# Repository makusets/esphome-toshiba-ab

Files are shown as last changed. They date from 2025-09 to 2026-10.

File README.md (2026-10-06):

# ESPHome Toshiba AB

ESPHome hardware and component support for Toshiba central air-conditioning and
ESTIA hydronic heat-pump systems that communicate over the two-wire **AB bus**.

> This project is not suitable for most split systems that are controlled only
> by an infrared remote.

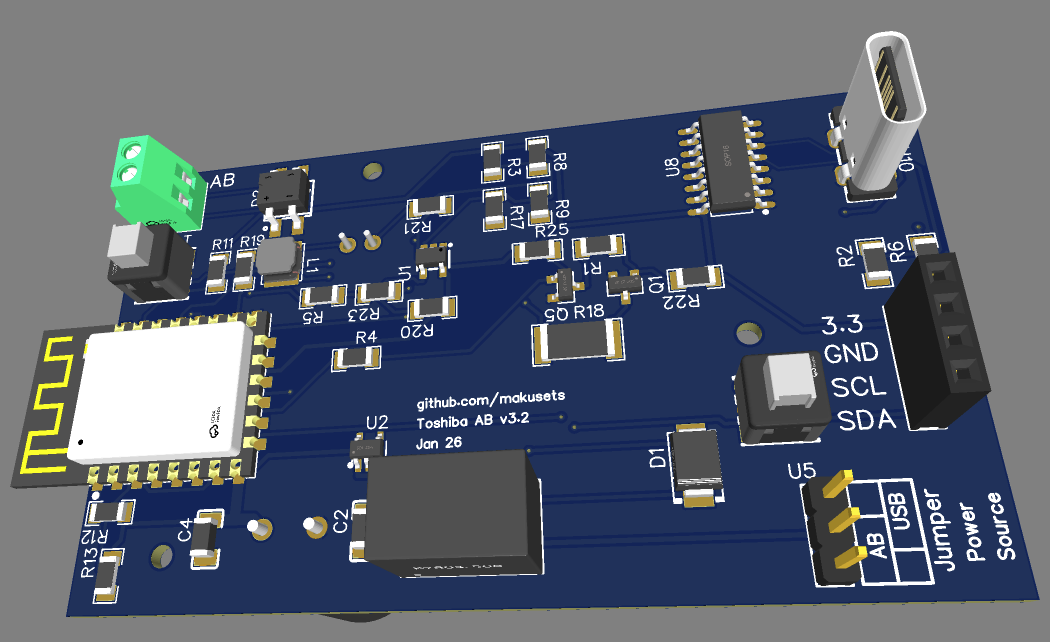
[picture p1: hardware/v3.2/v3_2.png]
Toshiba AB v3.2 board
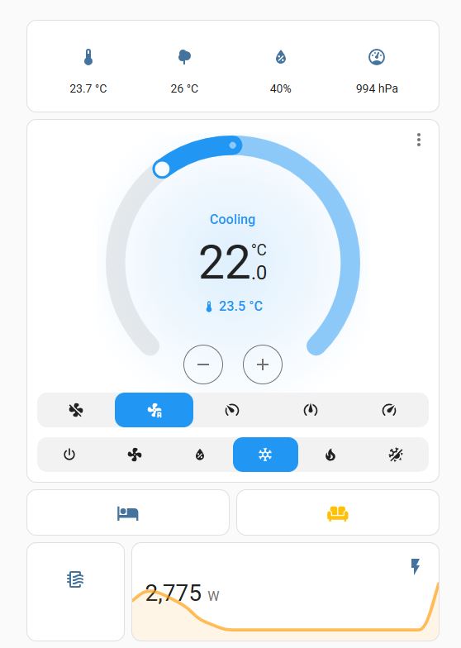
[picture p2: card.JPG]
Assembled Toshiba AB board
 

## Changelog

### July 2026 — TU2C and ESTIA R410A support

The TU2C protocol is now fully functional, thanks to contributions from
[@yvertman](https://github.com/yvertman) and
[@Dieghito72](https://github.com/Dieghito72).

Thanks to [@JuhaniVu](https://github.com/JuhaniVu), the first-generation Toshiba
ESTIA R410A frame format is fully implemented. Select `frame_format: estia` and
use a 2400 baud, 8N1 UART (`parity: NONE`). See the
[complete R410A configuration](estia_R410A.yaml).

### May 2026 — ESTIA R32 and protocol improvements

Thanks to [@7tobias](https://github.com/7tobias), Toshiba R32 ESTIA Series 1
systems are supported. The component can detect the normal TCC-Link, HM and
ESTIA R32/A0 formats, and address assignment avoids duplicate-address E09
errors. Thanks to [@mtthidoteu](https://github.com/mtthidoteu), HM-format support
and hardware UART operation improve compatibility and stability.

### January 2026 — autonomous mode

The component can operate without another wall controller, supports configurable
commercial-system read/write command modes and a filter-alert sensor, and has
more robust frame handling and logging. See the relevant complete YAML example
below for the optional settings.

### Hardware releases

- **v3.2:** revised UART pins, a 3300 µF 3.3 V rail capacitor, easier-to-solder
  USB-C, boot/reset buttons, a power-selection jumper and easier assembly.
- **D1 mini:** a simpler board designed with
  [@issalig](https://github.com/issalig), using RX D7 and TX D8.
- **v3:** wider AB-line voltage range, improved filtering, a comparator-based
  receiver and selectable AB/USB power.

## About this project

The component decodes traffic between a Toshiba indoor unit and its wired remote,
reports the system to ESPHome/Home Assistant, and sends commands as a wall remote
would. It supports:

- conventional **air-to-air systems** using classic TCC-Link, its HM variation,
  or the now fully functional TU2C protocol;
- **ESTIA hydronic systems**, including tested R410A and R32 generations;
- operation alongside a wall remote or, where supported, autonomous operation.

The hardware is an ESP8266/ESP-12 interface board designed in EasyEDA. It powers
from the AB line (or USB for initial flashing only, no comms) and converts the AB bus to
UART safely. **Do not connect the AB terminals directly to an ESP UART.**

### Hardware requirements and application range

You need a supported ESPHome board/interface from the [`hardware`](hardware/)
folder (or an electrically equivalent reader/writer circuit), access to the
unit's wired **A/B remote terminals**, and an ESPHome/Home Assistant installation.
The current board has been used with Toshiba central/commercial HVAC, multi-split
indoor units that expose an AB wired-controller connection, and ESTIA heat pumps.

Model names are useful hints, not guarantees: Toshiba has used different
protocols within related product ranges. Confirm that your unit has an AB port,
then use the selection tables below and the
[protocol/frame-format reference](docs/frame_formats.md).

## Start here: flash and connect the board

These essential installation steps are deliberately kept visible rather than
inside a collapsible section. Read the complete [hardware guide](docs/hardware.md)
before building a board or substituting components.

### 1. Flash ESPHome over USB

1. Start with [`example.yaml`](example.yaml), or copy the minimal configuration
   from the air-to-air/ESTIA section below. Add your normal ESPHome Wi-Fi, API,
   OTA and secrets settings.
2. Select the UART pins for your board: v3.2 uses TX `GPIO12` and RX `GPIO13`;
   v3 uses TX `GPIO10` and RX `GPIO13`; v1 uses TX `GPIO15` and RX `GPIO13`;
   D1 mini uses TX `D8` and RX `D7`. Also select the parity and optionally the
   `frame_format` required by your AC system in the tables below.
4. **Leave the AC's A/B wires disconnected.** With all power removed, put the
   board's power-selection jumper/switch (if fitted) in the **USB** position,
   then attach it to the computer with a data-capable USB cable.
5. In the ESPHome dashboard, open the device and choose **Install → Plug into
   this computer**, or run `esphome run your-device.yaml` from the ESPHome CLI
   and select the USB serial port. Follow ESPHome's
   [first-device connection guide](https://esphome.io/guides/physical_device_connection/)
   if the serial device is not detected.
6. For v3.2, if flashing does not start, disconnect USB, hold **BOOT**, reconnect
   USB while continuing to hold **BOOT**, and retry the installation. When the
   upload finishes, confirm that the device boots, joins Wi-Fi and appears in
   ESPHome/Home Assistant. Later firmware updates can be installed over Wi-Fi.

### 2. Connect the board to the AC system

> **Electrical safety:** completely isolate the HVAC system at the distribution
> board before opening the wired controller or indoor unit. Hazardous voltages
> may be present nearby. Never connect the A/B bus directly to ESP UART pins.

1. Disconnect USB and switch off/isolate the complete HVAC system.
2. Remove the wired controller cover and locate its two **A/B remote-bus**
   terminals (or use the indoor unit's documented A/B controller terminals).
   Loosen the terminal screws without removing the existing controller wires.
3. Run a two-core cable from those A and B terminals to the board's A and B
   screw terminals. The v1 board is polarity-sensitive, so match A to A and B
   to B; v3 and v3.2 accept either polarity.
4. With both USB and the AC still disconnected, move the board's power selector
   (if fitted) to **AB**. Never move the selector while either power source is
   connected.
5. Check the wiring, refit the controller cover, restore HVAC power, and inspect
   the ESPHome logs for valid frames and a connected state before sending any
   commands.

The board is connected **in parallel** with the wired controller; it does not
replace or interrupt the existing A/B pair. Autonomous operation without a wall
controller is an advanced option documented in
[`complete_example.yaml`](complete_example.yaml).

The A/B screws on a typical wired-controller PCB look like this:

A/B terminals on the back of a Toshiba wired controller

<details>
<summary><strong>Hardware design, construction, installation and case</strong></summary>

The recommended v3.2 board includes AB-line power conversion, noise filtering,
a comparator receiver and a transistor writer. Isolate the HVAC system before
opening a controller or changing AB wiring. Select USB power for initial flashing
and AB power only after USB power has been disconnected.

Board fabrication files, schematics, bills of materials, assembly advice,
installation steps and enclosure details are collected in the
[hardware guide](docs/hardware.md). Go directly to a board revision:

- [v3.2](hardware/v3.2/README.md) — recommended full board
- [D1 mini](hardware/D1%20mini/README.md) — simpler modular variant
- [v3](hardware/v3/README.md) and [v1](hardware/v1/README.md) — older revisions
- [all hardware and printable case files](hardware/)

</details>

<details>
<summary><strong>Air-to-air systems (conventional air conditioning)</strong></summary>

### Choosing a protocol

Air-to-air units use one of three supported AB protocol variations:

| Variation | Typical systems and examples | UART | `frame_format` |
| --- | --- | --- | --- |
| **TCC-Link** | Most established central/commercial systems. Tested examples include indoor `RAV-SM1103DT-A` and `MMD-AP0366BHP1-E` with `RBC-AMT32E`/`RBC-AMT54E` controllers; repository reports also include `RAV-SM802BT-E`. | 2400 baud, **8E1** (`EVEN`) | `auto` (recommended) or `normal` |
| **HM (TCC-Link variation)** | Newer RAV-HM/RAV-RM systems. Examples reported in this repository include `RAV-RM801BTP-E` + `RAV-GM801ATP-E`, `RAV-RM801KRTP-E`, and `RAV-HM561KRTP-E`. HM retains TCC-Link semantics but uses a different envelope. | 2400 baud, **8E1** (`EVEN`) | `auto` or `hm` |
| **TU2C** | Common in newer **U-series** systems; examples include `RAS-M16U2MUVG`, `RAS-M24U2DVG-E` and `M07U2DVG-E`. TU2C support is fully functional, but it is not auto-detected. | 2400 baud, **8N1** (`NONE`) | `tu2c` |

For byte-level differences, aliases and detection behavior, read
[Toshiba AB protocol frame formats](docs/frame_formats.md).

### Minimal ESPHome configuration

This is the complete component-specific portion for TCC-Link and HM. Add your normal
ESPHome device, Wi-Fi, API and OTA sections. For TU2C, change both highlighted
settings to `parity: NONE` and `frame_format: tu2c`.

```yaml
logger:
  baud_rate: 0

external_components:
  - source: github://makusets/esphome-toshiba-ab

uart:
  tx_pin: GPIO12       # GPIO10 on v3; GPIO15 on v1; D8 on D1 mini
  rx_pin: GPIO13       # D7 on D1 mini
  baud_rate: 2400
  parity: EVEN         # NONE for TU2C
  rx_buffer_size: 2048

climate:
  - platform: toshiba_ab
    name: "Toshiba AC"
    id: toshiba_ac
    frame_format: auto # use tu2c for TU2C systems or hm for HM systems
```

See [`complete_example.yaml`](complete_example.yaml) for autonomous operation,
addresses, temperature reporting, diagnostic sensors, power estimation and all
other air-to-air options. [`example.yaml`](example.yaml) is a ready-to-edit,
smaller device configuration.

### Optional BME280

The boards expose I²C so a BME280 can publish local temperature, humidity and
pressure. Its temperature can also be sent to the air conditioner as the room
temperature. The relevant I²C, sensor and `report_sensor_temp` YAML belongs in
the example configuration rather than this overview; see
[`complete_example.yaml`](complete_example.yaml).

</details>

<details>
<summary><strong>Hydronic systems (Toshiba ESTIA)</strong></summary>

### Tested generations and protocols

ESTIA changed protocol between the R410A and R32 generations. Both are supported,
but their UART parity and frame-format settings are not interchangeable.

| Generation | Protocol | Example/tested models | UART | `frame_format` |
| --- | --- | --- | --- | --- |
| **R410A / first generation** | First-generation ESTIA, TU2C-style wrapped frames | R410A ESTIA systems using first-generation wired controllers | 2400 baud, **8N1** (`NONE`) | `estia` (must be explicit) |
| **R32** | ESTIA A0 protocol | Series 1 `HWT-1101HRW-E` outdoor + `HWT-1101XWHT9W-E` indoor; `HWT-1102S21SM3W-E` is also reported in the repository | 2400 baud, **8E1** (`EVEN`) | `a0` |

### Minimal R410A configuration

```yaml
uart:
  tx_pin: GPIO15
  rx_pin: GPIO13
  baud_rate: 2400
  parity: NONE

climate:
  - platform: toshiba_ab
    name: "Toshiba Estia R410A"
    frame_format: estia
```

Use [`estia_R410A.yaml`](estia_R410A.yaml) for the complete R410A configuration.

### Minimal R32 configuration

```yaml
uart:
  tx_pin: GPIO15
  rx_pin: GPIO13
  baud_rate: 2400
  parity: EVEN

climate:
  - platform: toshiba_ab
    name: "Toshiba Estia R32"
    frame_format: a0
```

Use [`example_estia.yaml`](example_estia.yaml) for the complete R32 configuration,
including optional demand emulation, sensors and runtime switches.

### Optional BME280

A BME280 may be connected to the board's I²C header to expose local temperature,
humidity and pressure in ESPHome. ESTIA-specific control and polling do not
require it. Keep the actual BME280 configuration in the appropriate complete
YAML file if you choose to add one.

</details>

## Credits and thanks

This project builds on the difficult protocol-decoding and initial hardware work
by [@issalig](https://github.com/issalig) in
[`toshiba_air_cond`](https://github.com/issalig/toshiba_air_cond), and the initial
ESPHome component by [@muxa](https://github.com/muxa) in
[`esphome-tcc-link`](https://github.com/muxa/esphome-tcc-link).

Special thanks to [@7tobias](https://github.com/7tobias) for ESTIA R32 support,
[@JuhaniVu](https://github.com/JuhaniVu) for first-generation/R410A ESTIA support,
[@mtthidoteu](https://github.com/mtthidoteu) for HM support and hardware UART
improvements, and [@yvertman](https://github.com/yvertman) and
[@Dieghito72](https://github.com/Dieghito72) for their contributions to fully
functional TU2C support. Thanks also to every contributor and tester who has
shared hardware findings, models, captures, code and documentation.

## Boards on eBay

If you are after a fully finished product, I usually have some fully assembled boards that I am happy to sell. Search for "makusets" on eBay.

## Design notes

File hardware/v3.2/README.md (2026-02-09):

# v3.2 Jan 2026
# Ordering or building the board

You will need to build the compatible hardware. This folder contains all necessary files. I designed the board using EasyEDA online editor (free). All files are EasyEDA compatible format.
easyEDA_project.zip file can be imported onto EasyEDA editor to open the project with schematics and board design, make sure you use the 3.2 version once the project has been imported.

Alternatively, you can order the board from places like JLCPCB. You will need the 3 files included:

  - Gerber_v3_2.zip: This is the gerber file for the physical design of the board, if you only one the board made, that's all you need.
  - BOM_v3_2.csv: Contains the list of components (BOM). (needed if you want the full circuit board populated)
  - PaP_v3_2.csv: The information on where to place the component on the board. (needed if you want the full circuit board populated)

When ordering, make sure all the components that you want included are selected in the list.
I placed the electrolytic capacitors on the bottom side, so this will typically not be mounted if you are ordering the board from JLCPCB or similar. These are easily sourced and soldered by hand.
Use the 3D view to double check that all components appear on the board in the right orientation.

Alternatively, import easyEDA_project.zip and adjust it project to your needs. 

## Component shortfall

It often happens that components are out of stock or become unavailable and need to be replaced when uploading the BOM file. If you are not comfortable in doing so,
JLCPCB have the option of "parts sourced by JLCPCB" instead of "by customer". That should make it easy to replace shortfalls. Otherwise, use the search option and look for an equivalent component, AI is your friend and can help you find equivalent parts if in doubt. The 3D view on the next page can be useful to double check that you made the right choice and if any component needs to be reoriented.
The K78xx DCDC buck is a critical component, the board works fine with a DEXU branded one, EVSUN not good as it introduces a lot of noise in the AB line. Have not tried other brands, if you do, let me know.



# DIY tips

The internet is full of electronics sodering instructional tips and videos. I have nothing to add there, but I believe the board can be built with a bit of practice and some basic equipment, including a good soldering iron.

I personally did not use any magnifying device, reflow oven, or special equipment.

The two big capacitors are meant to be soldered at the back of the board and bended on its side, the case was designed with this in mind.

# Schematic

This is the schematic of the board.

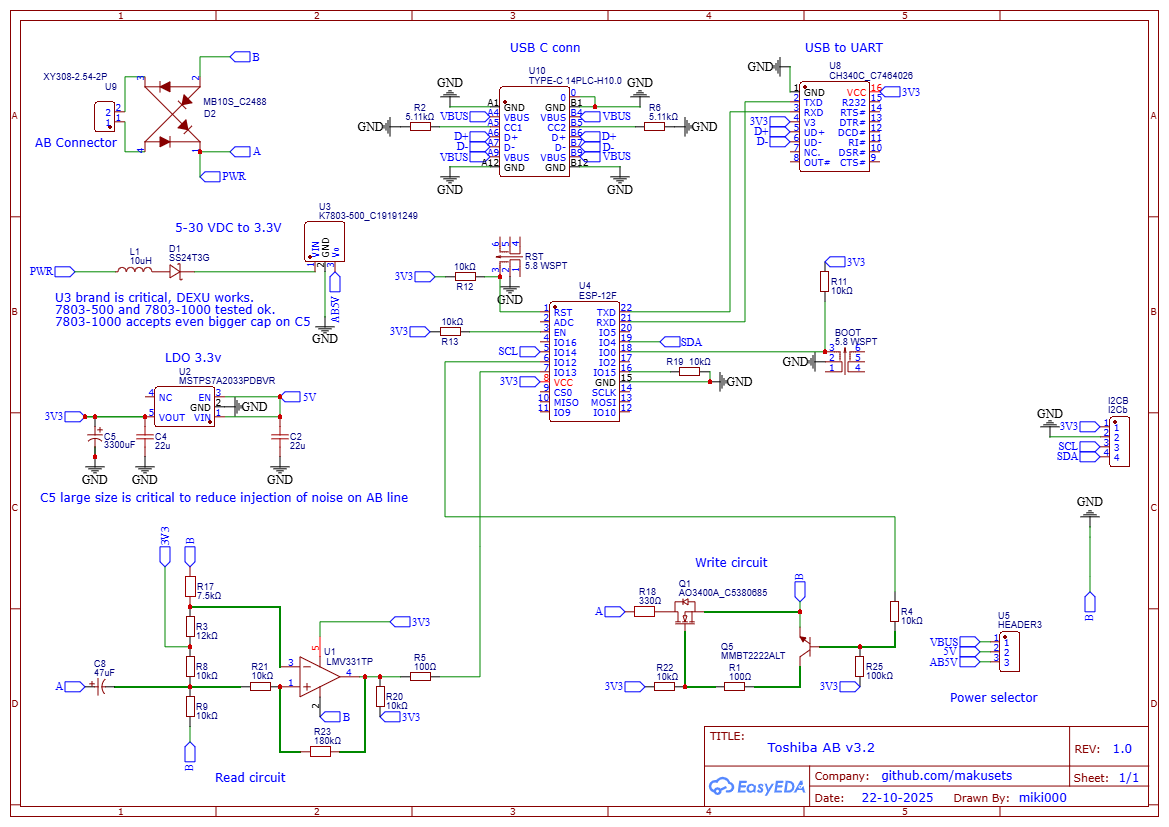
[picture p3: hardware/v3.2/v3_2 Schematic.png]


# Final product

This is how I installed it

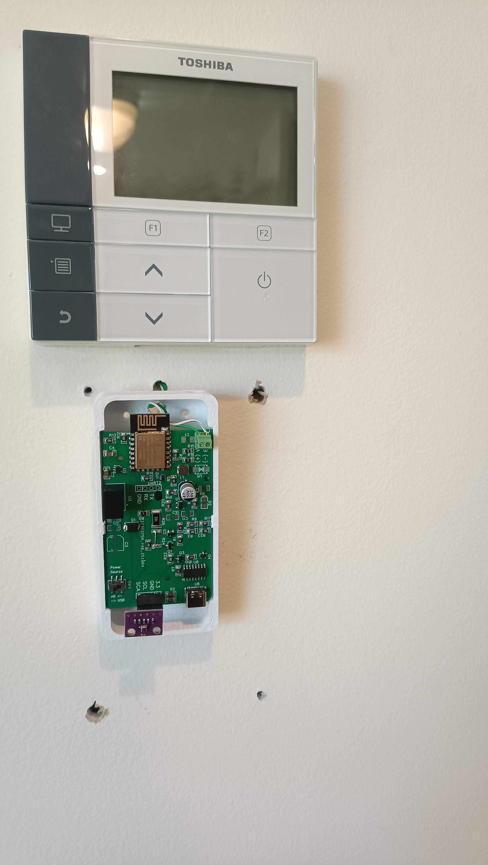
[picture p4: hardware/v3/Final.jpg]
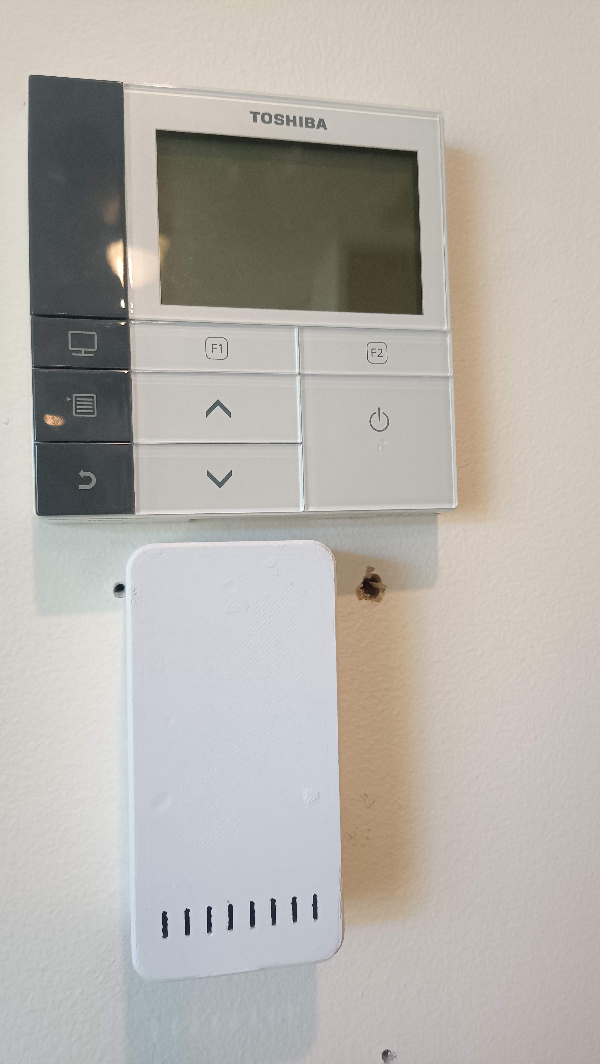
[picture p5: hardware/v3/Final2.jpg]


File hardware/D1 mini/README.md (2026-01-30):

# D1 mini Hardware

This folder contains the files required to build and assemble the D1 mini version of the board.

Contents

- `D1Mini.zip` — Gerber files for PCB fabrication (board layers, solder mask, silkscreen, drill files, etc.).
- `BOM_D1Mini.csv` — Bill of Materials: list of components, quantities and reference designators.
- `PP_D1Mini.csv` — Pick-and-place (Centroid) file used by automated assembly machines.
- `D1Mini.pdf` — Project schematic in PDF format.
- `D1Mini.png` — Project schematic as a PNG image (embedded below).

Notes

- Import the Gerber zip into your PCB manufacturer’s upload tool to produce PCBs.
- Use `BOM_D1Mini.csv` and `PP_D1Mini.csv` with your assembler or pick-and-place service.

# Schematic

The schematic for the D1 mini board is shown below.

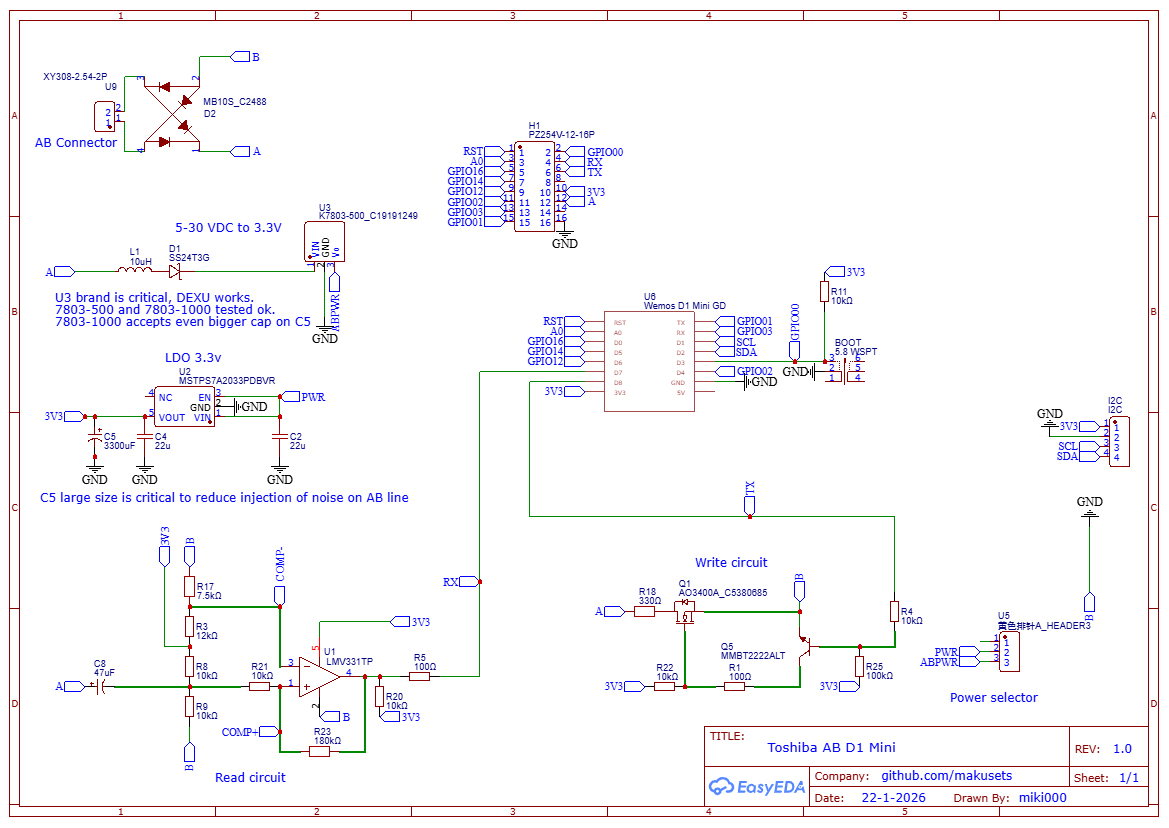
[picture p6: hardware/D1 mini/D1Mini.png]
D1 mini schematic


If the image does not render in your viewer, open `D1Mini.pdf` for a printable vector version.

---
Generated: January 30, 2026

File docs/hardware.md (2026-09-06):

# Toshiba AB hardware guide

The Toshiba AB bus is not a TTL UART. A reader/writer interface is required
between the A/B terminals and the ESP8266. This repository includes complete
fabrication files for several board revisions in the [`hardware`](../hardware/)
directory.

## Select a board

| Board | Use | UART pins | Documentation |
| --- | --- | --- | --- |
| v3.2 | Recommended integrated ESP-12 board | TX GPIO12, RX GPIO13 | [Build files and assembly](../hardware/v3.2/README.md) |
| D1 mini | Simpler modular board | TX D8, RX D7 | [Build files and assembly](../hardware/D1%20mini/README.md) |
| v3 | Previous integrated board | TX GPIO10, RX GPIO13 | [Build files and assembly](../hardware/v3/README.md) |
| v1 | Original board; polarity-sensitive AB input | TX GPIO15, RX GPIO13 | [Build files and assembly](../hardware/v1/README.md) |

Each board directory contains the available schematic, Gerbers, bill of
materials, pick-and-place data and/or editable EasyEDA project.

## Design

The v3/v3.2 design accepts the voltage range found on the AB line, filters power
and data noise, reads data through DC filtering and a comparator, and writes a
zero bit by pulling A toward B through a resistor, as Toshiba controllers do.
The bridge input makes these revisions insensitive to A/B polarity.

Wi-Fi current peaks are considerably higher than those of a wall controller.
For that reason the board uses a buck converter rather than only an LDO, followed
by a low-noise 3.3 V LDO and a large rail capacitor. The tested DEXU K7803-500 and
K7803-1000 converters work well. Component substitution—especially the buck
converter or filter capacitors—can introduce enough noise to corrupt AB traffic.

The I²C header supports an optional BME280 temperature, humidity and pressure
sensor, or another ESPHome-compatible I²C device.

## Building and first flash

1. Choose a board above and read its revision-specific README.
2. Upload its Gerber archive to a PCB fabricator. If ordering assembly, also
   supply that revision's BOM and pick-and-place file and verify component
   orientation in the fabricator's 3D preview.
3. Fit any through-hole capacitors or modules omitted by the assembly service.
4. For the first ESPHome flash, select **USB** power and connect USB. On v3.2,
   hold **BOOT** while applying USB power to enter flashing mode if necessary.
5. In the ESPHome dashboard choose **Install → Plug into this computer**, or run
   `esphome run your-device.yaml` and select the USB serial port. See ESPHome's
   [first-device connection guide](https://esphome.io/guides/physical_device_connection/)
   for USB driver and browser-installation details.
6. Confirm that the board boots and joins Wi-Fi. After the initial flash, normal
   updates can be installed over the air.

Never change the power selector while the board is powered. Disconnect both USB
and the AB line before moving the jumper or switch.

## Installation

> The indoor unit and wired controller may contain hazardous voltages nearby.
> Isolate the complete HVAC system at the distribution board before opening it.

1. Flash and validate the ESPHome board before connecting the AB line.
2. Completely isolate power to the HVAC system.
3. Remove the wired controller cover and loosen its A/B terminal screws, or use
   the unit's documented AB connection point. Leave the controller's existing
   wires in place: the interface board connects in parallel.
4. Wire A and B to the PCB. v1 is polarity-sensitive (A to A and B to B); v3 and
   v3.2 can be connected either way.
5. With USB disconnected, select **AB** power on boards that have a selector.
6. Reassemble the controller, restore HVAC power and inspect ESPHome logs for
   valid frames before sending commands.

The project emulates another wired controller. Address limits and coexistence
rules vary by system; avoid forcing addresses unless the normal auto-addressing
behavior does not work.

## Enclosure

A two-part printable enclosure is included in [`hardware/v3`](../hardware/v3/).
The v3.2 board fits the same case. STL files are ready for printing, and the
public Onshape source can be found by searching for `toshiba_esp_case` in
Onshape.

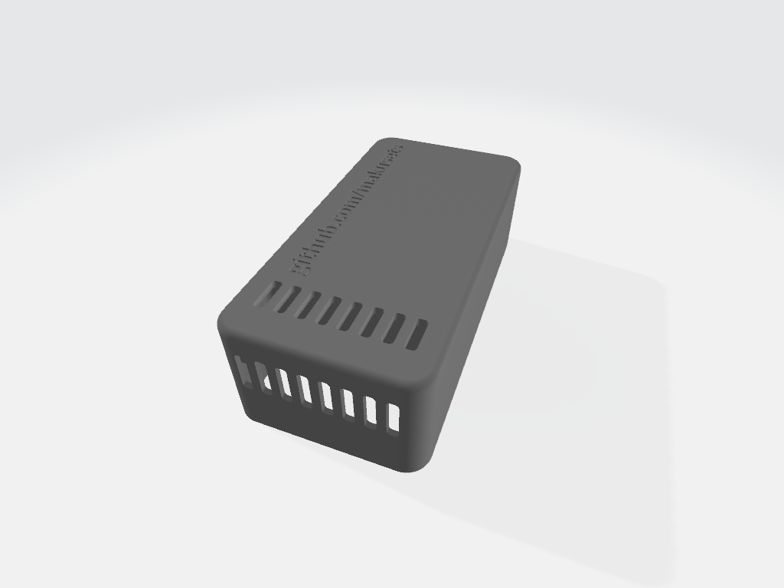
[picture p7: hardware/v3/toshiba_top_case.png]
Top of printable case
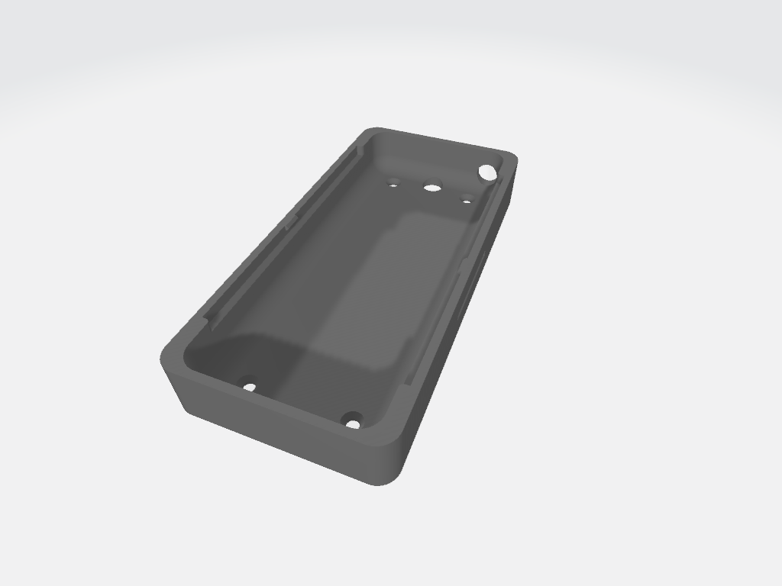
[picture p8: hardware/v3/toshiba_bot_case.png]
Bottom of printable case
 

## Next steps

Return to the [main README](../README.md) to select air-to-air or hydronic setup,
then use the correct UART parity and frame format for your system. Technical
protocol information is kept separately in
[`docs/frame_formats.md`](frame_formats.md).

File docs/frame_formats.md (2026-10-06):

# Toshiba AB protocols frame formats

This component can read several related Toshiba AB-bus protocols or frame formats. The default
configuration is `frame_format: auto`, which starts in the most common TCC-Link protocol
mode and switches to a more specific format if the component can identify one from live
traffic. Not all protocols are automatically identified.

## Quick selection guide

| `frame_format` value | Format | Typical use | UART parity | Auto-detected? | Notes |
| --- | --- | --- | --- | --- | --- |
| `auto` | Automatic | Recommended first try for most installs | See target format | N/A | Default. Starts as normal TCC-Link and confirms `normal` from traffic. |
| `n`, `normal`, `tcc-link` | Classic TCC-Link | Most central HVAC systems using the AB bus | `EVEN` | Yes | The component confirms this when it sees a valid master keepalive. |
| `hm` | HM / newer RAV-RM  | Newer HM-range/RAV-RM indoor units | `EVEN` | Maybe | Uses an `A0:00` prefix and different source/destination byte positions, then is normalised internally. |
| `a0`, `estia_a0` | Estia R32 protocol | R32 Estia heat pumps | `EVEN` | No, set explicitly | Very similar to HM, Uses two-byte CRC-16. |
| `u`, `tu2c`, `wrapped` | TU2C protocol | Newer U-series HVAC systems | `NONE` | No, set explicitly | Fully supported. Frames are prefixed with `F0:F0` and have a trailing `A0`. |
| `estia` | Estia R410A (first gen) TU2C variant | R410A Estia heat pumps | `NONE` | No, set explicitly | Uses the TU2C reader path and Estia-specific control/decoding logic. |

## Common fields used by frames

TCC-Link and the component's internal representation of frames (messages) use this
layout:

```text
SRC:DST:OPCODE1:LEN:DATA[0..LEN-1]:CRC
```

- `SRC` and `DST` are 8-bit source and destination addresses. Common values are
  `0x00` for the master/indoor unit and `0x40` for a wall remote or this ESP
  when emulating one. If `master` is omitted from YAML, the component keeps
  address auto-detection enabled and seeds the master address from the selected
  frame format (`0x00` for normal/HM/A0, `0x90` for TU2C, and `0x70` for
  first-generation Estia); an explicit `master` value is never overwritten by
  auto mode.
- `OPCODE1` identifies the broad message type, for example `0x10` ping,
  `0x11` parameter/status command, `0x15` read envelope, `0x18` ACK, `0x1A`
  sensor value, `0x1C` status, `0x55` temperature report, or `0x58` extended
  status.
- `LEN` is the number of data bytes between `LEN` and `CRC`.
- `CRC` is the classic one-byte checksum used by the existing TCC-Link decoder.

Example frames seen or generated by the component:

```text
01:52:11:04:80:86:A1:05:E4      # master parameter/status-style frame
01:52:11:04:80:86:48:01:09      # classic status example
40:00:15:07:08:0C:81:00:00:48:00:9F  # remote read/status envelope
42:00:11:04:08:89:<TEMP>:46:<CRC>    # external/room temperature report shape
```

External room-temperature reports always use source address `0x42`. The
wall-remote auto-addressing sequence skips `0x42` when resolving a collision so
that normal remote traffic cannot claim the temperature sensor's reserved
address.

## `normal` / classic TCC-Link

### Structure

```text
SRC:DST:OPCODE1:LEN:DATA...:CRC
```

The reader takes the fourth byte as `LEN`, expects `4 + LEN + 1` total bytes,
and validates the one-byte CRC. With the default frame filter enabled it ignores
obvious invalid normal frames whose first byte is greater than `0xA0`, which is
usually caused by electrical noise in the line, unless `filter_frames` is set to `false`.

CRC failure logs include the received checksum, the checksum calculated from the
captured bytes, and their XOR `syndrome`. A syndrome with one bit set is consistent
with a single-bit error somewhere in the frame (the XOR checksum cannot identify
which byte); a stable syndrome suggests a repeatable bit error, while changing
syndromes suggest broader signal-integrity or sampling problems.

### Auto-detection

Yes. When `frame_format: auto` is used, the reader initially parses frames as
classic TCC-Link. The component confirms the protocol after it receives a valid
master keepalive/ping frame.

### YAML

```yaml
uart:
  tx_pin: GPIO12
  rx_pin: GPIO13
  baud_rate: 2400
  parity: EVEN
  rx_buffer_size: 2048

climate:
  - platform: toshiba_ab
    name: "Toshiba AC"
    frame_format: auto   # default option, and can be omitted; or forced with: normal
```

## `hm` / HM-range systems

### Structure

Some HM/RAV-RM master systems send frames with a different structure in the frame format, and
with some extra bytes, for example:

```text
A0:00:OPCODE1:LEN:00:SRC_MODE:SRC:DST_MODE:DST:00:OPCODE2:PAYLOAD...:CRC
```

`LEN` is the number of data bytes between `LEN` and `CRC`
The values of bytes and their meaning is consistent with the TCC-Link protocol, but they are in different
positions. The firmware reader "converts" the read messages to the TCC-Link format and uses most of the
same code for interpretation.
However, CRC validation for HM frames is intentionally not checked because the HM CRC
algorithm has not yet been identified.

To send messages, the firmware just uses the normal TCC-Link format and the frames are accepted by the master.

### Auto-detection

Yes. In `auto` mode the component confirms `hm` when it sees a valid HM-shaped
frame from the master address.

### YAML

```yaml
uart:
  tx_pin: GPIO12
  rx_pin: GPIO13
  baud_rate: 2400
  parity: EVEN
  rx_buffer_size: 2048

climate:
  - platform: toshiba_ab
    name: "Toshiba HM AC"
    frame_format: auto   # default; or force with: hm
```

## `tu2c` / "U" series systems

### Structure

TU2C frames are easily identified by a two-byte prefix and one-byte suffix:

```text
F0:F0:TOTAL_LEN:SRC:DEST:C0:DATA...:CRC:A0
```

`TOTAL_LEN` includes the two `F0` prefix bytes, the length byte itself, and the
trailing `A0`. After the length byte, the reader stores the following bytes up
to but not including the final `A0` as the frame payload to decode messages.
TU2C command examples:

```text
F0:F0:0B:50:90:C0:01:21:02:CF:A0  # power-off example
F0:F0:0A:50:90:C0:49:0D:00:A0     # registration/query example
F0:F0:0C:50:90:C0:41:5C:90:F3:CC:A0  # keepalive example
```

### Auto-detection

No. The component knows how to interpret this format when selected, but `auto` does
not currently scan for TU2C protocol. Set it explicitly.

### YAML

```yaml
uart:
  tx_pin: GPIO12
  rx_pin: GPIO13
  baud_rate: 2400
  parity: NONE
  rx_buffer_size: 2048

climate:
  - platform: toshiba_ab
    name: "Toshiba TU2C AC"
    frame_format: tu2c   # aliases: u, wrapped
```

## `a0` / Estia R32 protocol

### Structure

The Estia R32 AO protocol is not the same as classic TCC-Link, even though it
uses the same AB-bus speed and even parity and the frames resemble the HM protocol.
A full frame looks like:

```text
A0:00:TYPE:LEN:00:SRC_MODE:SRC:DST_MODE:DST:DTYPE_H:DTYPE_L:DATA...:CRC_H:CRC_L
```

`SRC_MODE:SRC` and `DST_MODE:DST` are also referred as `SRC_H:SRC_L` and `DST_H:DST_L` 

The component processes bytes after the `A0:00` prefix. `LEN` is the
number of bytes between `LEN` and the two-byte CRC. The CRC is CRC-16/MCRF4XX
over the `A0:00` prefix plus the stored frame bytes except for the final CRC bytes.

Common SRC and DST addresses are `0x00` for the master, `0x40` for the remote, `0x41`
for the optional 0-10 V demand interface emulation, and `0xFE` for broadcast. Consistent
with Toshiba conventions.

The optional one-byte `remote:` and `master:` YAML values are also used for A0
without requiring separate A0 address options. The remote value is zero-extended
(`remote: 0x40` becomes `0x0040`, written as `00:40`) and the A0 master mode byte
`0x08` is prepended to the master value (`master: 0x00` becomes `0x0800`, written
as `08:00`). If omitted, those same `0x40` and `0x00` defaults apply.

Example frames:

```text
A0:00:11:08:00:00:40:08:00:00:41:22:<CRC_H>:<CRC_L>  # power-off command
A0:00:11:08:00:00:40:08:00:03:C0:02:<CRC_H>:<CRC_L>  # mode command (heat)
A0:00:15:0A:00:00:40:08:00:00:E8:C0:01:00:<CRC_H>:<CRC_L>  # data request
A0:00:18:26:00:SRC_H:SRC_L:DST_H:DST_L:00:E8:C1:01:00:DATA...:CRC_H:CRC_L
```

### Auto-detection

Yes. In `auto` mode, the component watches the byte stream for a complete
`A0:00` frame with a valid CRC-16 and master source address `0x0800`; it then
confirms `frame_format: a0`. Because Estia installs often need Estia-specific
options too, the Estia example forces `a0`.

### YAML

```yaml
uart:
  tx_pin: GPIO15
  rx_pin: GPIO13
  baud_rate: 2400
  parity: EVEN
  rx_buffer_size: 2048

climate:
  - platform: toshiba_ab
    name: "Toshiba Estia"
    frame_format: a0
    filter_frames: false
    autonomous: true       # optional: poll E8:C0/E8:C1 without another gateway
    demand_enabled: false  # optional: 0-10 V demand emulation
```

## `estia` / first-generation Estia R410A

### Structure

The `estia` option selects the component's first-generation Estia support path.
When `master` is omitted, this format defaults the master address to `0x70`
and keeps address auto-detection enabled.
It uses the TU2C-style format rather than the Estia R32 A0 style and parity NONE:

```text
F0:F0:TOTAL_LEN:SRC:DEST:DATA...:CRC:A0
```
`TOTAL_LEN` includes all bytes

Example frames:

```
F0:F0:11:70:FF:E0:C0:31:C3:80:10:90:52:66:00:EC:A0      Status frame
F0:F0:0B:60:70:E0:01:21:0C:E9:A0      Domestic Hot Water ON command
```

Internally, first-generation Estia and TU2C protocol use most of the same code.

### Auto-detection

No. Set `frame_format: estia` explicitly if you are using this.

### YAML

```yaml
uart:
  tx_pin: GPIO12
  rx_pin: GPIO13
  baud_rate: 2400
  parity: NONE
  rx_buffer_size: 2048

climate:
  - platform: toshiba_ab
    name: "Toshiba Estia first gen"
    frame_format: estia
    zone1_switch:
      name: "Estia Zone 1"
    dhw_boost:
      name: "Estia DHW Boost"
```

## Configuration aliases

The accepted values for `frame_format` are:

```text
auto
n, normal, tcc-link
hm
u, tu2c, wrapped
a0, estia_a0
estia
```

If you are unsure, start with the default `auto` and `parity: EVEN`. If your unit
is known to be a U-series/TU2C system, use `parity: NONE` and
`frame_format: tu2c`.

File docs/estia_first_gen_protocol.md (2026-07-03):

# Estia First-Generation (R410A) Protocol Frame Reference

## Overview

The **Estia first-generation protocol** (also called "Estia TU2C" in this codebase) is used by older Toshiba Estia R410A heat pumps. It uses a wrapped TU2C-style frame format with a simple 8-bit checksum.

**Key Characteristics:**
- **UART**: 2400 baud, 8N1 (NO parity)
- **Frame wrapping**: `F0:F0:[frame]:CRC:A0`
- **Checksum**: Simple 8-bit sum of frame bytes (modulo 256)
- **Master address**: 0x70 (default, auto-detectable)
- **Remote address range**: 0x60–0x69 (10 possible remotes)

---

## Frame Structure

All first-generation Estia frames follow this basic layout:

```
[0]            - Total frame length (includes all bytes from [0] to [3+payload+checksum])
[1]            - Source address
[2]            - Destination address
[3]            - Payload marker (usually 0xE0 for commands/status, 0x80 for sensor queries)
[4]            - Opcode/sub-command identifier
[5]            - Sub-opcode or data
[6..N-1]       - Payload data
[N-1]          - Checksum (8-bit sum of bytes [0..N-2])
```

**Checksum Calculation:**
```
checksum = (sum of all bytes from [0] to [N-2]) & 0xFF
```

---

## Frame Types

Frames are identified by examining specific byte positions: typically **[3]**, **[4]**, and **[5]** contain the frame signature.

### Master-Originated Frames

#### 1. **Master Status (0xE0 marker)**
**Signature**: `raw[3] == 0xE0 && raw[5] == 0x31`  
**Length**: ≥ 12 bytes  
**Meaning**: Master reports current operating state including temperatures and flags

**Frame layout:**
```
[0]         - Frame length (typically 0x13 or 0x14)
[1]         - Source: master address (0x70, or auto-detected)
[2]         - Destination address (remote address, e.g., 0x60)
[3]         - 0xE0 (status marker)
[4]         - (reserved)
[5]         - 0x31 (status signature)
[6]         - Flags byte: bit[0]=Zone1 active, bit[1]=DHW active
[7]         - Auto-mode and heating flags: bit[2]=auto mode active, bit[3..4]=heating indicators
[8]         - Hot water heating flags: bit[2]=resistor heating, bit[3]=pump heating
[9]         - DHW setpoint temperature (encoded as: °C = value/2 - 16)
[10]        - Zone 1 setpoint temperature
[11]        - (reserved/padding)
[12]        - Zone 1 water temperature (°C = value/2 - 16)
[13]        - (optional) Zone 2 setpoint
[14]        - (optional) Zone 2 water temperature
... [N-1]   - Checksum
```

**Auto-detected master**: If `master_address_auto_` is enabled and this frame signature appears, the source address is recorded as the master.

---

#### 2. **Master Keepalive**
**Signature**: `len == 0x0A && raw[5] == 0x3A`  
**Meaning**: Periodic heartbeat from master confirming it is alive

**Frame layout:**
```
[0]         - Frame length: 0x0A
[1]         - Source: master address (0x70, or auto-detected)
[2]         - Destination (remote address, e.g., 0x60)
[3..4]      - (data)
[5]         - 0x3A (keepalive signature)
... [N-1]   - Checksum
```

This frame resets the "master alive" timeout and confirms connection.

---

#### 3. **Master Sensor/Data Response**
**Signature**: `raw[4] == 0x80 && raw[5] == 0x5C`  
**Meaning**: Response to a sensor query from the remote; contains requested sensor value

**Frame layout:**
```
[0]         - Frame length
[1]         - Source: master address (0x70, or auto-detected)
[2]         - Destination (remote address)
[3]         - (marker)
[4]         - 0x80 (response marker)
[5]         - 0x5C (sensor data signature)
[6]         - High byte of 16-bit sensor value
[7]         - Low byte of 16-bit sensor value
[8]         - (optional additional data)
... [N-1]   - Checksum
```

The 16-bit value at [6:7] is used directly or scaled according to the query type.

---

#### 4. **Master Sensor Unavailable**
**Signature**: `raw[4] == 0x80 && raw[5] == 0xA2`  
**Meaning**: Sensor requested is not available or not supported

Clears the outstanding sensor query flag.

---

### Remote-Originated Frames

#### 5. **Remote Command (Generic)**
**Signature**: `raw[3] == 0xE0 && raw[4] == 0x01 && raw[5] == 0x21`  
**Meaning**: Remote control command

Common sub-commands at [6]:
- `0x03` – Zone 1 on
- `0x0A` – Zone 1 off
- `0x0C` – DHW (domestic hot water) on
- `0x08` – DHW off
- `0x01` – Auto mode on
- `0x00` – Auto mode off

---

#### 6. **Remote Setpoint Change Command**
**Signature**: `raw[3] == 0xE0 && raw[4] == 0x01 && raw[5] == 0x23`  
**Meaning**: Remote requests temperature setpoint change

**Frame layout:**
```
[0]         - Frame length
[1]         - Source: remote address (0x60–0x69)
[2]         - Destination: master (0x70)
[3]         - 0xE0 (command marker)
[4]         - 0x01 (command type)
[5]         - 0x23 (setpoint change signature)
[6]         - (reserved)
[7]         - (reserved)
[8]         - (reserved)
[9]         - 0xA0 (setpoint marker)
[10]        - Target temperature (encoded as: °C = value/2 - 16)
... [N-1]   - Checksum
```

---

#### 7. **Remote Status (Echo)**
**Signature**: `raw[3] == 0xE0 && raw[5] == 0x31`  
**Meaning**: Remote reports its own status (mirrors master status structure)

---

#### 8. **Remote Sensor/Data Query**
**Signature**: `len == 0x0C && raw[4] == 0x41 && raw[5] == 0x5C`  
**Meaning**: Remote requests sensor data from master

**Frame layout:**
```
[0]         - Frame length: 0x0C
[1]         - Source: remote address (0x60–0x69)
[2]         - Destination: master (0x70)
[3]         - (marker)
[4]         - 0x41 (query marker)
[5]         - 0x5C (data request signature)
[6]         - Sensor/data ID to query (e.g., 0xEF for DHW current temperature)
... [N-1]   - Checksum
```

---

#### 9. **Remote Timer Read Query**
**Signature**: `raw[3] == 0xE0 && raw[4] == 0x41 && raw[5] == 0x5C`  
**Meaning**: Remote queries operating hour counters or timer information

---

## Address Space

| Address Range | Meaning | Default | Notes |
|---|---|---|---|
| 0x70 | Master (indoor unit) | 0x70 | Can auto-detect from status frames |
| 0x60–0x69 | Remotes | 0x60 (default for first remote) | Up to 10 remotes supported; collision avoidance increments address |

**Auto-detection Rules:**
- If no master address is set and a status frame (0xE0:0x31) is received, the source becomes the master
- If a remote address collides with outgoing commands, the remote address is auto-incremented up to 0x69
- Once confirmed, addresses persist across frames

---

## Temperature Encoding

Throughout the first-generation Estia protocol, temperatures are encoded as:

```
value = (°C + 16) × 2

Decoding:
°C = value / 2 - 16

Examples:
  20°C  = (20 + 16) × 2 = 0x48 (72)
  22.5°C = (22.5 + 16) × 2 = 0x4D (77)
  0°C   = (0 + 16) × 2 = 0x20 (32)
  -10°C = (-10 + 16) × 2 = 0x0C (12)
```

---

## Checksum Validation

Before processing any frame, always validate the checksum:

```cpp
uint8_t calculated = (sum of bytes [0..N-2]) & 0xFF;
uint8_t received = raw[N-1];

if (calculated != received) {
  // CRC fail — discard frame
  return;
}
```

---

## Protocol Behavior

### Initialization & Auto-Detection

When `master_address_auto_` is enabled:

1. Component watches for incoming frames
2. On receipt of a master-status frame (0xE0:0x31), the source address is recorded as the master
3. Keepalive frames (0xE0:0x3A) with matching keepalive signature confirm master identity
4. **Remote address auto-detect**: If a received remote ping has `src == remote_address_` and `remote_address_auto_` is true, the next address up to `0x69` is chosen (collision avoidance)

### Master Alive Timeout

- On **any** frame from master, timestamp `last_master_alive_millis_` is updated
- After `LAST_ALIVE_TIMEOUT_MILLIS` (~16s) with no master frame, component reports disconnected
- Connected binary sensor is updated accordingly

### Sensor Queries

1. Component sends a query: `raw[4]==0x41, raw[5]==0x5C, raw[6]=sensor_id`
2. Master responds with sensor data (0x80:0x5C) or "unavailable" (0x80:0xA2)
3. Query is marked complete; next polled sensor can be queried
4. If no response within timeout (~2.5s), query is abandoned

---

## Known Sensor Query IDs

| Sensor ID | Description | Notes |
|---|---|---|
| 0xEF | DHW current temperature | Common request for hot water status |
| 0x0A | (TBD) | Estia first-gen specific |
| (others)  | Zone setpoints, outdoor temp, etc. | Depends on unit configuration |

---

## Common Frame Examples

### Status Update from Master
```
13:70:60:E0:00:31:81:A0:84:4D:48:00:48:48:CC
```
- Length: 13 (19 bytes)
- Source: 70 (master)
- Dest: 60 (remote)
- Status marker: E0, signature: 31
- Byte[6] = 81: Zone1 active (bit 0), DHW active (bit 1)
- Byte[7] = A0: Auto-mode and heating flags
- Byte[8] = 84: Hot water heating flags
- Byte[9] = 4D: DHW setpoint = 4D/2 - 16 = 22.5°C
- Byte[10] = 48: Zone 1 setpoint = 48/2 - 16 = 20°C
- Byte[11] = 00: Padding
- Byte[12] = 48: Zone 1 water temp = 48/2 - 16 = 20°C
- Checksum: CC

---

### DHW On Command from Remote
```
0B:60:70:E0:01:21:0C:00:00:00:E8
```
- Length: 0B (11 bytes)
- Source: 60 (remote)
- Dest: 70 (master)
- Signature: E0:01:21 (remote command)
- Byte[6] = 0C: DHW on command
- Bytes[7-10]: Padding
- Checksum: E8

---

### DHW Off Command from Remote
```
0B:60:70:E0:01:21:08:00:00:00:E4
```
- Length: 0B (11 bytes)
- Source: 60 (remote)
- Dest: 70 (master)
- Signature: E0:01:21 (remote command)
- Byte[6] = 08: DHW off command
- Checksum: E4

---

### Setpoint Change Command (22.5°C)
```
0F:60:70:E0:01:23:00:00:00:A0:4D:00:00:00:C5
```
- Length: 0F (15 bytes)
- Source: 60 (remote)
- Dest: 70 (master)
- Signature: E0:01:23 (setpoint change)
- Byte[6-8]: Reserved (00:00:00)
- Byte[9] = A0: Setpoint marker
- Byte[10] = 4D: Target temp = 4D/2 - 16 = 22.5°C
- Checksum: C5

---

### Sensor Query (DHW Current Temperature)
```
0C:60:70:E0:41:5C:EF:00:00:00:5F
```
- Length: 0C (12 bytes)
- Source: 60 (remote)
- Dest: 70 (master)
- Signature: E0:41:5C (sensor query)
- Byte[6] = EF: Query sensor ID (DHW current temperature)
- Bytes[7-9]: Padding/reserved
- Checksum: 5F

---

### Master Sensor Response
```
0A:70:60:80:80:5C:00:42:00:6C
```
- Length: 0A (10 bytes)
- Source: 70 (master)
- Dest: 60 (remote)
- Signature: 80:80:5C (sensor response)
- Bytes[6-7] = 00:42: 16-bit value = 0x0042 = 66 (encoded temperature ≈ 17°C)
- Byte[8]: Padding
- Checksum: 6C

Decoded temperature: 66/2 - 16 = 33 - 16 = 17°C

---

### Master Keepalive
```
0A:70:60:00:00:3A:00:00:00:F0
```
- Length: 0A (10 bytes)
- Source: 70 (master)
- Dest: 60 (remote)
- Signature: 3A (keepalive)
- Bytes[3-4]: Data (00:00)
- Bytes[7-9]: Padding
- Checksum: F0

---

### Sensor Not Available Response
```
0A:70:60:80:80:A2:00:00:00:8C
```
- Length: 0A (10 bytes)
- Source: 70 (master)
- Dest: 60 (remote)
- Signature: 80:80:A2 (sensor not available)
- Bytes[6-9]: Data/padding
- Checksum: 8C

---

## Error Handling

### Checksum Failures

- Log frame with error detail
- Discard frame
- Continue listening for next frame

### Invalid Lengths

- If `frame->raw[0] < 7` or too large: skip
- If calculated `raw_len` exceeds buffer: return

### Auto-Detection Collisions

- If a received remote ping source matches current remote address and `remote_address_auto_` is true, increment remote address
- Report collision in logs

### Timeouts

- Sensor query timeout (default ~2.5s): clear outstanding flag, allow next query
- Master alive timeout (default ~16s): report disconnected state

---

## Debugging & Logging

Key logging points in the code:

1. **Frame label**: Shows frame type identification (Master Keepalive, Remote Command, etc.)
2. **Raw checksum output**: Helps verify protocol understanding
3. **Sensor query tracking**: Logs sensor ID and raw value for each response
4. **Address auto-detection**: Logs master/remote addresses when discovered

Enable `DEBUG` log level on the `TAG` to see all frame details.

---

## References

- Source: `components/toshiba_ab/toshiba_ab.cpp` — `process_received_data_estia_first_gen_()` (line 3264)
- Frame building: `toshiba_ab.cpp` — `make_estia_first_gen_frame()` (line 3203)
- Commands: `send_estia_first_gen_*()` family of functions
- Header constants: `components/toshiba_ab/toshiba_ab.h` (lines 29–31)

---

## Appendix: Byte-by-Byte Identification Quick Reference

| Byte Position | Value Range | Meaning |
|---|---|---|
| [0] | 07–20 | Frame length |
| [1] | 70 | Master address (fixed, or auto-detected) |
| [1] | 60–69 | Remote address range |
| [3] | E0 | Command/status marker |
| [3] | 80 | Data/response marker |
| [4] | 01 | Command type |
| [4] | 41 | Query/request type |
| [4] | 80 | Data response |
| [5] | 21 | Generic command |
| [5] | 23 | Setpoint change command |
| [5] | 31 | Status frame |
| [5] | 3A | Keepalive signature |
| [5] | 5C | Sensor data/query |
| [5] | A2 | Sensor not available |

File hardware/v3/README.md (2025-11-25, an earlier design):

# v3 Board. Oct 2025
# Ordering or building the board

You will need to build the compatible hardware. This folder contains all necessary files. I designed the board using EasyEDA online editor (free). All files are EasyEDA compatible format.
v3_project_easyEDA.zip file can be imported onto EasyEDA editor to open the project with schematics and board design.

Alternatively, you can order the board from places like JLCPCB. You will need the 3 files included:

  - Gerber_v3.zip: This is the gerber file for the physical design of the board
  - BOM_v3.csv: Contains the list of components (BOM).
  - PickAndPlace_v3.csv: The information on where to place the component on the board.

When ordering, make sure all components are selected in the list (components that incur an extra fee, need to be manually ticked)
Use the 3D view to double check that all components appear on the board.

Alternatively, the file v3_project_easyEDA.zip contains a copy of the project that you can import into EasyEDA to edit. 

## Component shortfall

It often happens that components are out of stock or become unavailable and need to be replaced when uploading the BOM file. If you are not comfortable in doing so,
tick the option of "parts sourced by JLCPCB" instead of "by customer". That should make it easy to replace shortfalls. Otherwise, use the search option and look for an equivalent component. The 3D view on the next page can be useful to double check that you made the right choice.
The K78xx DCDC buck is a critical component, the board works fine with a DEXU branded one, EVSUN not good as it introduces noise in the AB line. Have not tried other brands, if you do, let me know.

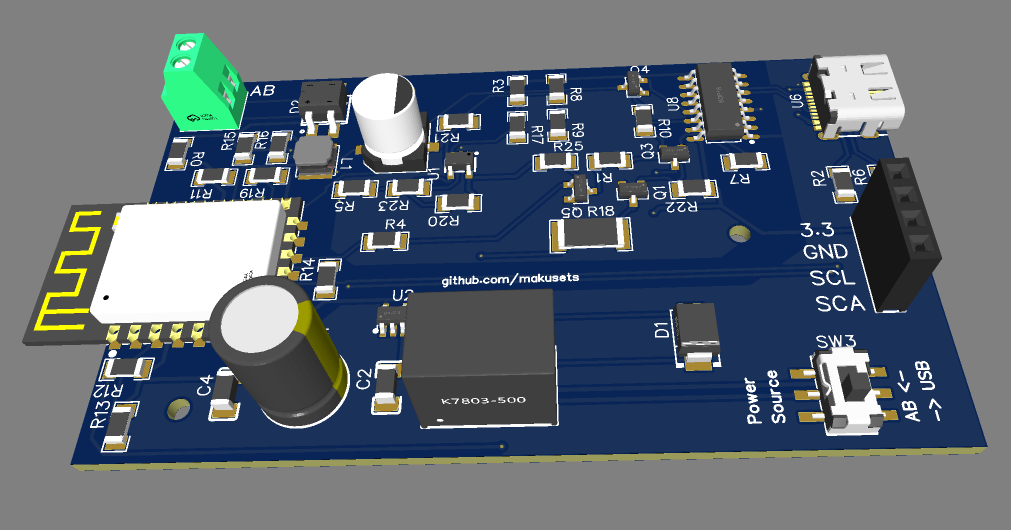
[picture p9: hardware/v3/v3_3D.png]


# DIY tips

The internet is full of electronics sodering instructional tips and videos. I have nothing to add there, but I believe the board can be built with a bit of practice and some basic equipment, including a good soldering iron and possibly a hot air soldering gun to make it easier soldering the USB-C connector (or continue reading for options).

I personally did not use any magnifying device, reflow oven, or special equipment.

USB-C connector: this is the hardest bit to solder and it might be easier done with a hot air station. In any case, the connector is only there for the initial flashing of the firmware. Alternatively, one could flash the initial firmware on the ESP12 using a flashing board and get rid of the USB-C connector together with the USB to UART IC, the transistors and the resistors. (U6, U8, R7, R10, R12, R11, Q3 and Q4). Updates can be done OTA once the board is up and running.

[USB-C programmer on AliExpress](https://www.aliexpress.com/item/1005007750007503.html)

The big capacitor is meant to be soldered at the back of the board and bended on its side, the case was designed with this in mind.

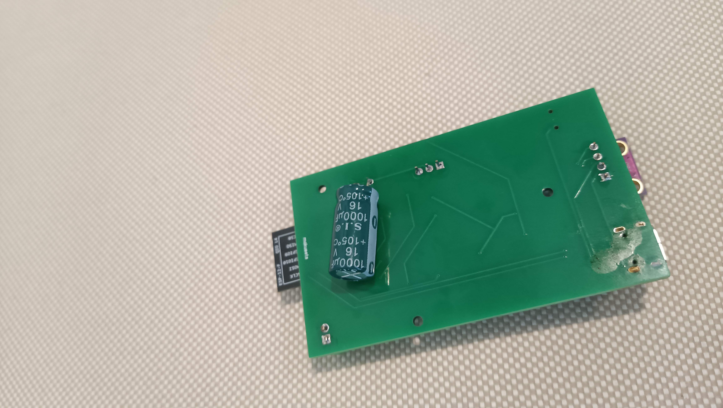
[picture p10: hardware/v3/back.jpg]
      

# Schematic

This is the schematic of the board.



# Final product

This is how I installed it



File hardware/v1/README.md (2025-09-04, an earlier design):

# Ordering or building the board

You will need to build the compatible hardware. This folder contains all necessary files. I designed the board using EasyEDA online editor (free). All files are EasyEDA compatible format.
EasyEDA.zip file can be imported onto EasyEDA editor to open the project with schematics and board design.

Alternatively, you can order the board from places like JLCPCB. You will need the 3 files included:

  - Gerber.zip: This is the gerber file for the physical design of the board
  - BOM_01.csv or BOM_02.csv: Just choose one of them, they are slightly different format to maximise compatibility. They contain the list of components (BOM).
  - PickAndPlace.csv: The information on where to place the component on the board.

When ordering, make sure all components are selected in the list (components that incur an extra fee, need to be manually ticked)
Use the 3D view to double check that all components appear on the board.

Alternatively, the file EasyEDA_Toshiba.zip contains a copy of the project that you can import into EasyEDA to edit. 

## Component shortfall

It often happens that components are out of stock or become unavailable and need to be replaced when uploading the BOM file. If you are not comfortable in doing so,
tick the option of "parts sourced by JLCPCB" instead of "by customer". That should make it easy to replace shortfalls. Otherwise, use the search option and look for an equivalent component. The 3D view on the next page can be useful to double check that you made the right choice.



# Schematic

This is the schematic of the board.



# Final product

This is how I installed it

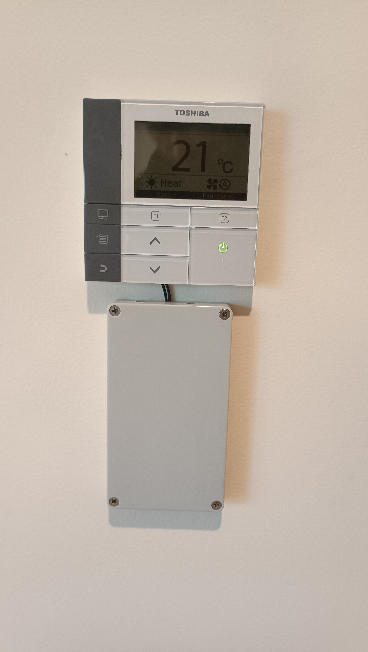
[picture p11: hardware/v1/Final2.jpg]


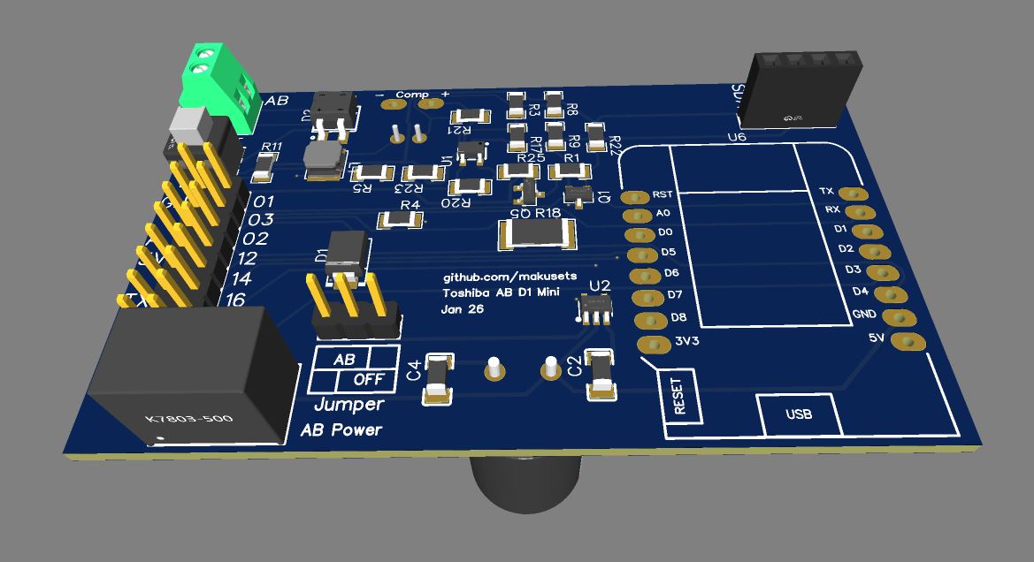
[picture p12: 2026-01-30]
hardware/D1 mini/D1Mini.JPG

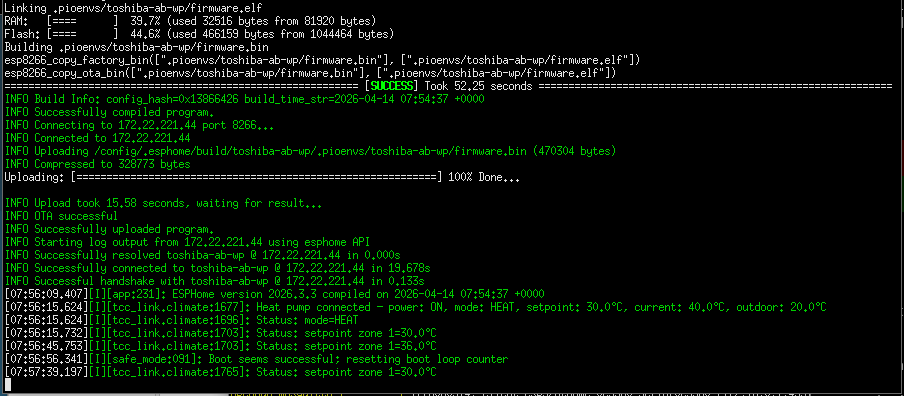
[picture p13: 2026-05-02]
docs/estia-log.png

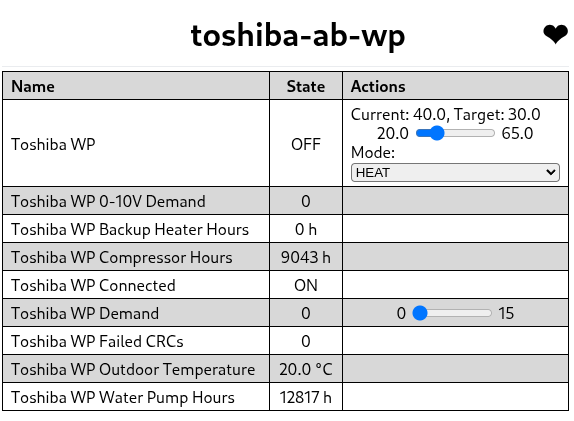
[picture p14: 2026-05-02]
docs/estia-esphome.png

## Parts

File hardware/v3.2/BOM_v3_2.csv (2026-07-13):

ID | Name | Designator | Footprint | Quantity | Manufacturer Part | Manufacturer | Supplier | Supplier Part | Price
1 | MMBT2222ALT | Q5 | SOT-23-3_L2.9-W1.3-P1.90-LS2.4-BR | 1 | MMBT2222ALT3G | onsemi(安森美) | LCSC | C402270 | 0.021
2 | HEADER3 | U5 | HDR-TH_3P-P2.54-V-M-1 | 1 | 黄色排针A_HEADER3 | null | LCSC | C9900019266
3 | 47uF | C8 | CAP-TH_BD6.3-P2.50-D1.0-FD | 1 | 50YXJ47M6.3X11 | Rubycon(红宝石) | LCSC | C88791 | 0.068
4 | 3300uF | C5 | CAP-TH_BD13.0-P5.00-D0.6-FD | 1 | CD2883381CM1320VFL | HRK(鸿瑞凯电子) | LCSC | C7493818 | 0.092
5 | 12kΩ | R3 | R1206 | 1 | 1206W4F1202T5E | UNI-ROYAL(厚声) | LCSC | C17912 | 0.004
6 | 5.8 WSPT | RST,BOOT | SW-TH_6P-L5.8-W5.8-P2.00-LS4.5-TL_K8-5851E-L1 | 2 | 5.8 WSPT | SHOU HAN(首韩) | LCSC | C5379898 | 0.067
7 | TYPE-C 14PLC-H10.0 | U10 | USB-C-TH_SHOUHAN_TYPE-C-14PLC-H10.0 | 1 | TYPE-C 14PLC-H10.0 | SHOU HAN(首韩) | LCSC | C3151746 | 0.252
8 | 7.5kΩ | R17 | R1206 | 1 | FRC1206J752 TS | FOJAN(富捷) | LCSC | C17978 | 0.004
9 | MB10S_C2488 | D2 | MBS_L4.7-W3.8-P2.40-LS7.0-TL | 1 | MB10S-50MIL | MDD(辰达半导体) | LCSC | C2488 | 0.026
10 | 180kΩ | R23 | R1206 | 1 | FRC1206J184 TS | FOJAN(富捷) | LCSC | C2907436 | 0.003
11 | K7803-500_C19191249 | U3 | PWRM-TH_K7803-500 | 1 | K7803-500 | DEXU(德旭电子) | LCSC | C909766 | 1.197
12 | 10kΩ | R8,R9,R19,R4,R22,R20,R21,R11,R12,R13 | R1206 | 10 | 1206W4F1002T5E | UNI-ROYAL(厚声) | LCSC | C17902 | 0.004
13 | 330Ω | R18 | R2512 | 1 | FRC2512F3300TS | FOJAN(富捷) | LCSC | C2934068 | 0.031
14 | 10uH | L1 | IND-SMD_L4.0-W4.0 | 1 | FHD4020S-100MT | cjiang(长江微电) | LCSC | C602032 | 0.11
15 | 100Ω | R5,R1 | R1206 | 2 | RC1206JR-07100RL | YAGEO(国巨) | LCSC | C113307 | 0.004
16 | AO3400A_C5380685 | Q1 | SOT-23-3_L2.9-W1.3-P1.90-LS2.4-BR | 1 | AO3400A | FUXINSEMI(富芯森美) | LCSC | C5380685 | 0.037
17 | 100kΩ | R25 | R1206 | 1 | 1206W4J0104T5E | UNI-ROYAL(厚声) | LCSC | C25647 | 0.003
18 | LMV331TP | U1 | SOT-23-5_L2.9-W1.6-P0.95-LS2.7-BR | 1 | LMV331TP | TECH PUBLIC(台舟) | LCSC | C41431784 | 0.107
19 | 22u | C4,C2 | C1206 | 2 | CL31A226KAHNNNE | SAMSUNG | LCSC | C12891 | 0.048
20 | MSTPS7A2033PDBVR | U2 | SOT-23-5_L3.0-W1.7-P0.95-LS2.8-BL | 1 | MSTPS7A2033PDBVR | MSKSEMI(美森科) | LCSC | C2862740 | 0.13
21 | SS24T3G | D1 | SMB_L4.6-W3.6-LS5.3-RD | 1 | SS24T3G | onsemi(安森美) | LCSC | C85393 | 0.194
22 | XY308-2.54-2P | U9 | CONN-TH_XY308-2.54-2P | 1 | XY308-2.54-2P | XINLAIYA(新莱亚) | LCSC | C557685 | 0.247
23 | I2Cb | I2CB | HDR-TH_4P-P2.54-V-F | 1 | PM2.54-1*4 | ZHOURI(洲日) | LCSC | C5116530 | 0.085
24 | 5.11kΩ | R2,R6 | R1206 | 2 | CR1206F45111G | LIZ(丽智电子) | LCSC | C137249 | 0.004
25 | ESP-12F | U4 | WIRELM-SMD_ESP-12F | 1 | ESP-12F | DOIT(四博智联) | LCSC | C82891 | 2.398
26 | CH340C_C7464026 | U8 | SOP-16_L10.0-W3.9-P1.27-LS6.0-BL | 1 | CH340C | WCH(南京沁恒) | LCSC | C7464026

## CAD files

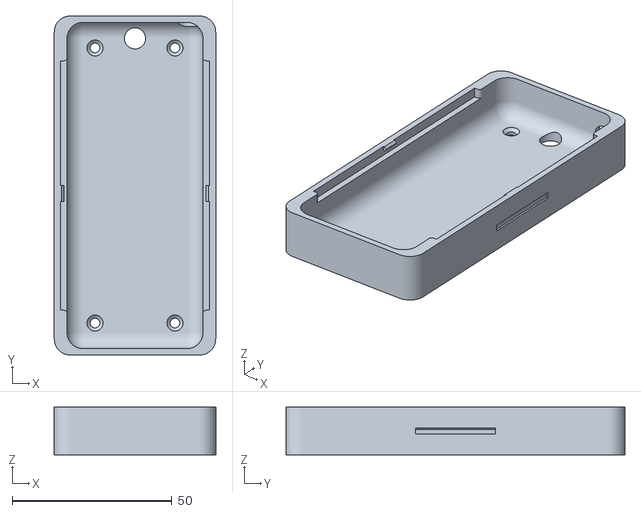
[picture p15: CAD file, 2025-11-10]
hardware/v3.2/toshiba_bot_case.stl
50.5 x 106.0 x 15.0

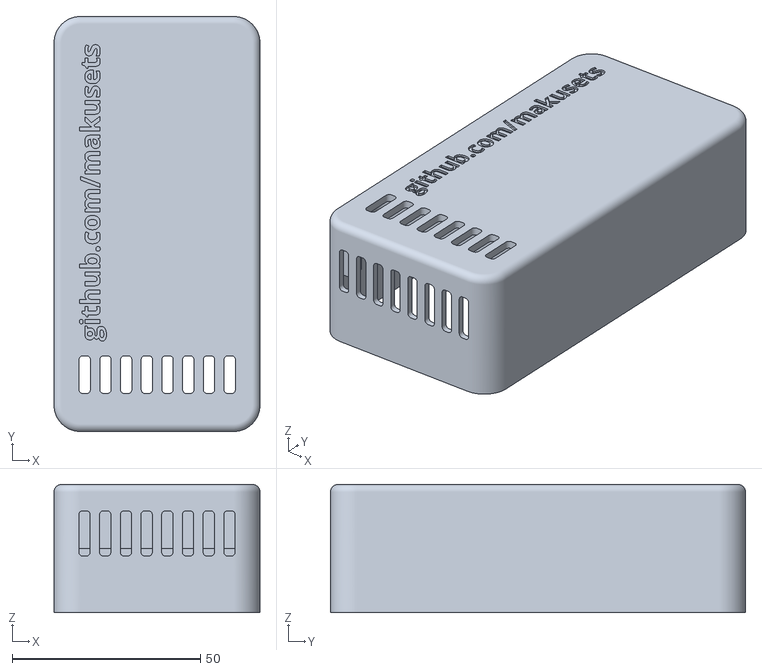
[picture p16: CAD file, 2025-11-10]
hardware/v3.2/toshiba_top_case.stl
54.7 x 110.2 x 34.0

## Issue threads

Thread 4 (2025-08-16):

Failed to build without BME sensor

tchlyah, 2025-08-16:
Hi,

I'm trying to compile the project using a simple yaml file without BME sensor, but it fails with the following message:

```
/.platformio/packages/toolchain-xtensa/bin/../lib/gcc/xtensa-lx106-elf/10.3.0/../../../../xtensa-lx106-elf/bin/ld: .pioenvs/living/src/esphome/components/toshiba_ab/toshiba_ab.cpp.o:(.text._ZN7esphome10toshiba_ab16ToshibaAbClimate4loopEv+0x8): undefined reference to `bme280_temp'                                                                                                                     
collect2: error: ld returned 1 exit status                                                                                                                                                                 
*** [.pioenvs/living/firmware.elf] Error 1
```

Am I missing something from the configuration file ?

### ESPHome YAML file

```yaml
substitutions:
  name: living
  friendly_name: living

esphome:
  name: ${name}
  friendly_name: ${friendly_name}

esp8266:
  board: esp12e

logger:
  baud_rate: 0  #disable hardware UART log to use pins for UART communication with the AC unit
  level: DEBUG

external_components:
  - source:
      type: git
      url: https://github.com/makusets/esphome-toshiba-ab

uart:
  tx_pin: GPIO15
  rx_pin: GPIO13
  baud_rate: 2400
  parity: EVEN

climate:
  - platform: toshiba_ab
    name: AC
    id: ac
    connected:
      name: "Toshiba AC Connected"
    master: 0x01 # Master ID in Toshiba protocol, optional, default is 0x00, for some units needs to be set to 0x01

ota:
  - platform: esphome
    password: !secret ota_pwd

wifi:
  #  use_address: ${ip_address}
  ssid: !secret wifi_ssid
  password: !secret wifi_password
  ap:
    ssid: "${friendly_name} Fallback"
    password: !secret ota_pwd

## Captive portal when wifi connection fails
captive_portal:

```

tchlyah, 2025-08-16:
Only adding a sensor using the exact same name it is expecting works:

```yaml
sensor:
  - platform: bme280_i2c
    temperature:
      name: "Indoor Temperature"
      id: bme280_temp
      oversampling: 1x
```

tchlyah, 2025-08-16:
Also, how to read the logs to check what is going on ? Since `logger.baud_rate = 0`, I get this when I try to get the logs:

```

```

Closed 2025-08-16.

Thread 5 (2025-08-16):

Protocol mismatch? Toshiba Carrier (40VD048S / MCC-1631 CN41) – need help debugging

tchlyah, 2025-08-16:
Hi @makusets, pinging @issalig as well 👋

First of all, thanks to both of you for your amazing work on these projects.

I’ve just received the boards and installed one on **Toshiba Carrier ducted unit** (Carrier model **40VD048S-6S-TEE**, board **MCC-1631**, using CN41 A/B).

### The situation
- The good news: the board boots and communicates.
- The bad news: the **protocol doesn’t seem to match** – the AC is always reported as OFF, and the only thing that seems to come through is the **remote temperature** (though not 100% accurate).

### Logs
Here are some extracts from my session:

<details>
<summary><b>Init</b></summary>

```text
[14:59:01][I][app:149]: ESPHome version 2025.7.5 compiled on Aug 16 2025, 14:58:38
[14:59:01][C][wifi:613]: WiFi:
[14:59:01][C][wifi:434]:   Local MAC: 40:91:51:57:17:68
[14:59:01][C][wifi:439]:   SSID: 'Keto Wifi-2.4'
[14:59:01][C][wifi:442]:   IP Address: 192.168.1.75
[14:59:01][C][wifi:446]:   BSSID: C4:E5:32:8F:C5:EB
[14:59:01][C][wifi:446]:   Hostname: 'living'
[14:59:01][C][wifi:446]:   Signal strength: -49 dB ▂▄▆█
[14:59:01][C][wifi:455]:   Channel: 1
[14:59:01][C][wifi:455]:   Subnet: 255.255.255.0
[14:59:01][C][wifi:455]:   Gateway: 192.168.1.1
[14:59:01][C][wifi:455]:   DNS1: 192.168.1.1
[14:59:01][C][wifi:455]:   DNS2: 0.0.0.0
[14:59:01][C][logger:246]: Logger:
[14:59:01][C][logger:246]:   Max Level: DEBUG
[14:59:01][C][logger:246]:   Initial Level: DEBUG
[14:59:01][C][logger:252]:   Log Baud Rate: 0
[14:59:01][C][logger:252]:   Hardware UART: UART0
[14:59:01][C][i2c.arduino:073]: I2C Bus:
[14:59:01][C][i2c.arduino:074]:   SDA Pin: GPIO2
[14:59:01][C][i2c.arduino:074]:   SCL Pin: GPIO14
[14:59:01][C][i2c.arduino:074]:   Frequency: 50000 Hz
[14:59:01][C][i2c.arduino:090]:   Recovery: bus successfully recovered
[14:59:01][I][i2c.arduino:100]: Results from bus scan:
[14:59:01][I][i2c.arduino:102]: Found no devices
[14:59:01][C][uart.arduino_esp8266:118]: UART Bus:
[14:59:01][C][uart.arduino_esp8266:119]:   TX Pin: GPIO15
[14:59:01][C][uart.arduino_esp8266:120]:   RX Pin: GPIO13
[14:59:01][C][uart.arduino_esp8266:122]:   RX Buffer Size: 256
[14:59:01][C][uart.arduino_esp8266:124]:   Baud Rate: 2400 baud
[14:59:01][C][uart.arduino_esp8266:124]:   Data Bits: 8
[14:59:01][C][uart.arduino_esp8266:124]:   Parity: EVEN
[14:59:01][C][uart.arduino_esp8266:124]:   Stop bits: 1
[14:59:01][C][uart.arduino_esp8266:131]:   Using hardware serial interface.
[14:59:01][C][bme280_i2c.sensor:025]:   Address: 0x76
[14:59:01][C][bme280.sensor:181]: BME280:
[14:59:01][E][bme280.sensor:184]: Communication failed
[14:59:01][C][bme280.sensor:193]:   IIR Filter: OFF
[14:59:01][C][bme280.sensor:194]:   Update Interval: 30.0s
[14:59:01][C][bme280.sensor:196]:   Temperature 'Indoor Temperature'
[14:59:01][C][bme280.sensor:196]:     State Class: 'measurement'
[14:59:01][C][bme280.sensor:196]:     Unit of Measurement: '°C'
[14:59:01][C][bme280.sensor:196]:     Accuracy Decimals: 1
[14:59:01][C][bme280.sensor:196]:     Device Class: 'temperature'
[14:59:01][C][bme280.sensor:197]:     Oversampling: 1x
[14:59:01][C][bme280.sensor:198]:   Pressure 'Indoor Pressure'
[14:59:01][C][bme280.sensor:198]:     State Class: 'measurement'
[14:59:01][C][bme280.sensor:198]:     Unit of Measurement: 'hPa'
[14:59:01][C][bme280.sensor:198]:     Accuracy Decimals: 0
[14:59:01][C][bme280.sensor:198]:     Device Class: 'pressure'
[14:59:01][C][bme280.sensor:199]:     Oversampling: 1x
[14:59:01][C][bme280.sensor:200]:   Humidity 'Indoor Humidity'
[14:59:01][C][bme280.sensor:200]:     State Class: 'measurement'
[14:59:01][C][bme280.sensor:200]:     Unit of Measurement: '%'
[14:59:01][C][bme280.sensor:200]:     Accuracy Decimals: 0
[14:59:01][C][bme280.sensor:200]:     Device Class: 'humidity'
[14:59:01][C][bme280.sensor:201]:     Oversampling: 2x
[14:59:01][E][component:141]:   bme280_base is marked FAILED: unspecified
[14:59:01][C][tcc_link.climate:507]: TCC Link:
[14:59:01][C][tcc_link.climate:571]: ClimateTraits:
[14:59:01][C][tcc_link.climate:572]:   [x] Visual settings:
[14:59:01][C][tcc_link.climate:572]:       - Min temperature: 18.0
[14:59:01][C][tcc_link.climate:572]:       - Max temperature: 29.0
[14:59:01][C][tcc_link.climate:572]:       - Temperature step:
[14:59:01][C][tcc_link.climate:572]:           Target: 0.5
[14:59:01][C][tcc_link.climate:581]:           Current: 0.5
[14:59:01][C][tcc_link.climate:593]:   [x] Supports current temperature
[14:59:01][C][tcc_link.climate:602]:   [x] Supports action
[14:59:01][C][tcc_link.climate:605]:   [x] Supported modes:
[14:59:01][C][tcc_link.climate:607]:       - OFF
[14:59:01][C][tcc_link.climate:607]:       - HEAT_COOL
[14:59:01][C][tcc_link.climate:607]:       - COOL
[14:59:01][C][captive_portal:099]: Captive Portal:
[14:59:01][C][esphome.ota:073]: Over-The-Air updates:
[14:59:01][C][esphome.ota:073]:   Address: living.local:8266
[14:59:01][C][esphome.ota:073]:   Version: 2
[14:59:01][C][esphome.ota:080]:   Password configured
[14:59:02][C][safe_mode:018]: Safe Mode:
[14:59:02][C][safe_mode:019]:   Boot considered successful after 60 seconds
[14:59:02][C][safe_mode:019]:   Invoke after 10 boot attempts
[14:59:02][C][safe_mode:019]:   Remain for 300 seconds
[14:59:02][C][web_server.ota:224]: Web Server OTA
[14:59:02][C][api:207]: API Server:
[14:59:02][C][api:207]:   Address: living.local:6053
[14:59:02][C][api:212]:   Using noise encryption: YES
[14:59:02][C][mdns:122]: mDNS:
[14:59:02][C][mdns:122]:   Hostname: living
[14:59:02][D][tcc_link.climate:083]: Enqueue command: 40:00:17:08:08:80:EF:00:2C:08:00:6A:76
[14:59:02][D][tcc_link.climate:083]: Write frame: 40:00:17:08:08:80:EF:00:2C:08:00:6A:76
 ```
</details>

<details>
<summary><b>Remote Temperature</b></summary>

```text
[14:55:03][D][tcc_link.climate:725]: Received data from remote:
[14:55:03][D][tcc_link.climate:083]: Remote temperature: 40:04:55:06:08:81:00:78:00:00:E6
[14:55:03][D][tcc_link.climate:736]: Remote temperature: 25.0 °C
 ```
</details>

<details>
<summary><b>Ping</b></summary>

```text
[13:39:33][D][tcc_link.climate:725]: Received data from remote:
[13:39:33][D][tcc_link.climate:083]: Remote PING: 40:04:15:07:08:0C:81:00:00:48:00:9B
 ```
</details>

<details>
<summary><b>AC Off</b></summary>

```text
[15:10:33][D][tcc_link.climate:083]: Failed frame: 04:FE:58:12:80:81:48:A0:80:00:60:79:E9:00:33:32:00:00:00:00:00:00:00
[15:10:34][W][tcc_link.climate:549]: Sensor query timed out; clearing outstanding flag (timeouts=24)
[15:10:38][W][tcc_link.climate:781]: CRC check failed
[15:10:38][D][tcc_link.climate:083]: Failed frame: DB:DB:FF:04:FE:10:02:80:8A
[15:10:43][D][tcc_link.climate:763]: Received data from unknown source: 04
[15:10:43][D][tcc_link.climate:083]: Unknown source: 04:FE:10:02:80:8A:E2
[15:10:48][D][tcc_link.climate:763]: Received data from unknown source: 04
[15:10:48][D][tcc_link.climate:083]: Unknown source: 04:FE:10:02:80:8A:E2
[15:10:53][D][tcc_link.climate:763]: Received data from unknown source: 04
[15:10:53][D][tcc_link.climate:083]: Unknown source: 04:FE:10:02:80:8A:E2
 ```
</details>

<details>
<summary><b>Cool On, target temperature 22, low FAN</b></summary>

```text
[15:14:58][D][tcc_link.climate:763]: Received data from unknown source: 04
[15:14:58][D][tcc_link.climate:083]: Unknown source: 04:FE:10:02:80:8A:E2
[15:15:01][W][READER:228]: Went over buffer
 ```
</details>

<details>
<summary><b>Cool On, target temperature 22, high FAN</b></summary>

```text
[15:15:45][D][tcc_link.climate:083]: Failed frame: 00:09:00:40:00:29:AC:49:74:F7:7B:FF:FF:FF:FF:FF:FF:FE:04:A4:00:00:00:00:00:00:00:00:30:80:08:51:85:F9:E8:5F:FF:FF:EF:FB:FF:EF:FF:FF:FF:FF:FF:FF:FB:FF:FF:FF:FF:FF:FF:00:00:00:00:00:00:00:00:00:00:00:00:00:00
 ```
</details>

<details>
<summary><b>Init</b></summary>

```text

 ```
</details>

<details>
<summary><b>Switch from Cool to Dry mode</b></summary>
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
Lectere, 2025-08-29:
Tayeb send me one, so I hope I can go and start testing soon!, keep you posted!

tchlyah, 2025-09-09:
While waiting for the new board to arrive, I'm thinking about moving the board to the AC motherboard directly rather than near the thermostat.

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

According to the motherboard diagram, it seems that the CN41 (AB line) is the black wires near the blue ones in the right. WDYT @makusets, is it safe to connect the board directly to those, or it's better to stick to the thermostat itself ?

In case the new board fails, what if I can use some kind of power source from the motherboard directly? WDYT ?

tchlyah, 2025-09-09:
Alright, I’ll give that a try. Although using a USB power source might complicate things! I’ll probably need an electrician for this since I’m not comfortable with that kind of installation.

Still no news of the new board?

makusets, 2025-09-16:
> Alright, I’ll give that a try. Although using a USB power source might complicate things! I’ll probably need an electrician for this since I’m not comfortable with that kind of installation.
>
> Still no news of the new board?

@tchlyah, I received the boards and components earlier last week. The new design incorporate some adjustable components to be able to tune the board to different voltages. However, I am still having trouble with the adjustments, it works alright through USB, but I am still having trouble when powered from the AB line. I am still working on it. I will keep you updated of the progress.

tchlyah, 2025-09-27:
Hi @makusets,

So I've installed the board in the motherboard directly with USB power module, it worked perfectly in the living room, but not in the other rooms 😞 I tried changing the master id to multiple values, but nothing worked. The remote temperature is accurate, but no control is working!

Here the logs:

[logs_kitchen-ac_logs.txt](https://github.com/user-attachments/files/22571663/logs_kitchen-ac_logs.txt)

[logs_kitchen-ac_logs-2.txt](https://github.com/user-attachments/files/22571664/logs_kitchen-ac_logs-2.txt)

makusets, 2025-09-27:
Not sure what you mean @tchlyah, so the esp board is in the indoor unit, and what is it that doesn't work? The original Toshiba wall remotes? I assume you have more than one of them?

Btw, I'm away for a few weeks, so i haven't spend much time working on the new revision, I'll go back to it when back home.

Miquel

tchlyah, 2025-09-27:
I have 5 units, each one have one thermostat (or wall remote). The one that I tested first, the living room, is working perfectly. But not the others, I shared with you the logs of the Kitchen one, but all the others report the same logs.

makusets, 2025-09-28:
So, you have a ducted system yeah? 1 outdoor unit and one indoor unit in the ceiling space or similar? Or do you have 5 different ducted systems each with its own indoor unit completely independent?
For what I can see, the kitchen remote uses master id 0x02, that's different of from 0x04 from the living room. You would need to change that for it to work.

makusets, 2025-09-28:
I just modified the code to auto detect the master address. If you don't configure a master address or if it is detected that it doesn't match the messages, it will automatically be corrected. Can you try removing the master: option from the yaml file and see what happens. I have not tested it extensively so let me know if it fails.

tchlyah, 2025-09-28:
It's a VRF system (XPower) with 5 different ducted system each with its own indoor unit and remote control.

Yes, 0x02 was my very first try, then I tested some few values including 0x40, doesn't make sens but I was desperate. The logs I shared in the message just above are the latest with 0x02.

I have also set the correct values for the two others, same results, the board is only able to receive remote data (Ping and Temperature as you can see from the logs)

Ok I'll test the new code but I doubt it will male any difference, as I believe that the Master id is correct from the logs.

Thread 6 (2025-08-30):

Can't find EASYEDA source file

yverty, 2025-08-30:
Hi, could you provide the EASYEDA file.

I would like to change the form factor of the PCB.

Thanks in advance.

BR

Julien

Lectere, 2025-08-31:
Is it not inside the zip file? (the gerber zip)

makusets, 2025-09-04:
Sorry @yverty, didn't see your message earlier. I have now uploaded the project for you to edit as you wish. I am in the process of upgrading the board to be more reliable. New version should be available in a week or two if it all works well. In case you prefer to wait.

yvertyman, 2025-09-05:
> Sorry [@yverty](https://github.com/yverty), didn't see your message earlier. I have now uploaded the project for you to edit as you wish. I am in the process of upgrading the board to be more reliable. New version should be available in a week or two if it all works well. In case you prefer to wait.

Thanks very much for anwsering and the project. I'll wait for the new version.

BR

Closed 2025-10-05.

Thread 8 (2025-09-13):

Unable to use code in custom board

makusets, 2025-09-13:
Hi @litinoveweedle,

I just openned a new issue for this to keep it tidier.

So, when you say that the board does not past the slef test, what do you mean with that? Do you have the original RBC-AMTU31-E connected too? Or are you trying to connect your board as standalone? Also, when you say it resets the AB line, what do you see? Does the toshiba RBC wall temote go blank and restart?

I will have a look at your schematic now.

Miquel

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

 _Originally posted by @litinoveweedle in [#5](https://github.com/makusets/esphome-toshiba-ab/issues/5#issuecomment-3287018388)_

makusets, 2025-09-13:
Have you tried putting 1 or 2 decent size diode in series on the A line at hte entrance to lower the voltage?

litinoveweedle, 2025-09-28:
Hello,

sorry for long pause, but I have unfortunately other tasks to attend ;-o

I do not have updates on the AC board, but I have updates on the other board for Toshiba TCC protocol controlled Heat Pump. It does use same Issalig base schema, but this time without embedded power supply circuit, therefore eliminating probable issue with it. The board is using POE powered ESP-32 (Olimex ESP32-POE board). Controlled Toshiba Heat Pump is Estia Indoor unit HWS-804XHWT9-E1 (HWS-1404WWHT9-E1), remote controller HWS-AMS11E.

The used board schema is therefore very simple:

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

I am using this ESPhome integration: https://github.com/vakkeli/toshiba_uart_ctrl

The issue is unfortunately same - it seems that I am unable to read anything from the TCC link, as the voltages are again above @issalig board design ranges. TCC high is around 16.8V, TCC low when set by original Toshiba controller seems to be 1V lower - around 15.8V.

This is the signal without board connected to TCC bus:

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

With the board connected, the TCC high drops to around 16.6V, while TCC low set by the Toshiba controller remains around 15.8V. You can once again see signal from the Toshiba controller here:

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

Here I captured both signal from the Toshiba controller (on the right) and probably from the board (on the left). You can clearly see differences in the signal quality - high under and overshoots but also in different TCC low levels - board set TCC low at about 1.6V bellow TCC high:

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

Even if I set ESPhome UART debug, the board doesn't read anything from the TCC bus, as probably higher than expected TCC levels set read optocoupler always on. This is second Toshiba device with higher TCC levels than the @issalig based board expects.

Do you think it would be OK to use instead of the D2 in the read circuit trimmer potentiometer as voltage diver, to make the board suitable for the different voltages? With the write circuit it could probably stay same, as I thing that Toshiba devices will be OK with lower values, but It would be probably better to use similar principles where the TCC low could be made tunable. What is your opinion?

makusets, 2025-09-28:
That's very valuable info, thanks. I had the same idea, my second iteration which I was working on did actually incorporate some potentiometers to be able to adjust the voltage; however, if the voltage on the line changes again (if adding another wall remote for example, or changing the model) the problem appears again and needs to be tuned again. I'm now working on a more standard approach where the read is done after filtering the DC out, as is common in power over data lines. I think it's a more robust solution. I'm still playing with the potentiometer boards as I have them around, but not sure that's the definitive solution. When I finish the third iteration, I'll compare the results and see.
I'm confident that the solution is not far.

litinoveweedle, 2025-09-28:
When you mentioned removing DC part from the signal, do you use [bias tree](https://en.wikipedia.org/wiki/Bias_tee) or op amp?

makusets, 2025-09-29:
> When you mentioned removing DC part from the signal, do you use [bias tee](https://en.wikipedia.org/wiki/Bias_tee) or op amp?
I am using a conventional DC coupling filter followed by a comparator to have clean 3.3v logic. I tried the opamp approach in my version 2 board with the potentiometers, but it still requires adjusting to the voltage.

issalig, 2025-09-29:
Hi, I've been following your progress and it looks promising. I am thinking to make another version of my circuit but I am not an electronics engineer and I do not really know what's the best solution.

I have seen solutions using comparator LM393 and/or opamps. I am waiting for some components and once here I will start the experiments.

issalig, 2025-09-29:
This page (https://burro.hatenablog.com/entry/2022/07/18/230300) describes the schematics of the RBCAMT31
Maybe, we can just use this circuit or get inspiration.

litinoveweedle, 2025-09-29:
Very nice ...

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

I can see and understand the input diode bridge to prevent polarity, the power source part and also decoupling DC part from the signal by 100uF capacitor...

makusets, 2025-09-29:
> This page (https://burro.hatenablog.com/entry/2022/07/18/230300) describes the schematics of the RBCAMT31
> Maybe, we can just use this circuit or get inspiration.

Thanks mate, that's really useful. My second iteration used a similar design, but this should be better and tested. I'll punch some values in ltspice and see what I get.
Bear in mind that Toshiba used an LDO to power its board, which I think it's not possible to power the ESP as the heat generated would be too high. So the buck converter option available to us will introduce noise which needs to be dealt with.

litinoveweedle, 2025-09-29:
I just quickly connected my original board with the TSR DC-DC converter to the LAB PSU and oscilloscope and there is not much noise. I can image PSU has beefy capacitors on the output, but so I will test it on the TCC line as well later on. But so far it doesn't seems so bad.

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

makusets, 2025-10-01:
That sound good, but to be reliable you should measure it with the load (so the switching frequency is the same). The ESP draws about 30mA average with pulses in the 100mA range when using wifi. This creates pulsating current which the DCDC buck have to deal with.

makusets, 2025-10-02:
@issalig, just finished the new design, the schematics you attached were very helpful. I have ordered new boards and will test them as soon as i get them. I believe this time I got it right. I have just followed the toshiba design: comparator for the read circuit, with a DC filtering capacitor and just sink current through a 330ohm for the write circuit. We will see.

issalig, 2025-10-02:
Great news!
Regarding the different voltage levels I have seen this circuit for door entry systems that uses a digital pot MCP4017 and the does some SW tuning.
https://github.com/Elektroarzt/simplebus2-mqtt-bridge/tree/main?tab=readme-ov-file#Hardware

litinoveweedle, 2025-10-02:
@issalig I think that using a comparator solves the issues with the differences in the TCC voltages.

@makusets is your new board powered from the TCC? Also I like using bridge rectifier as polarity protection, as TCC bus claims to be polarity insensitive. Last questions will there be any galvanic separation of TCC part from the ESP (like previously on issaligs board)?

makusets, 2025-10-02:
I haven't added the rectifier, but you are right, that should be a good idea. My board does have a diode though that would not work if plugged in rerverse. I will think about adding it if i need to change anything else. I did some simulation in LTSpice and the latest iteration that i just ordered should accept any voltage and would work with a drop of only 0.2V in the line when data is received. Regarding isolation, not the esp will not be isolated from the bus, this is not possible using the comparator approach. This is the same approach as Toshiba uses. issalig board is powered independently through usb and uses optocouplers, hence the isolation. I power my current board from the AB line, and although I still use the optocouplers at the moment, the isolation is lost as the DCDC buck has common ground. I moved awat from the optos and the only option I see is using optocouplers and an isolated DCDC buck; however, I cannot see the need for that.

makusets, 2025-10-02:
BTW, you cannot power an esp12 directly from 5V. There's no regulator to 3.3v on that board.

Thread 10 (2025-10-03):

Ordering current board without AB line power source

tchlyah, 2025-10-03:
Hi @makusets,

While waiting for the new board revision to be ready, I might need to order the current board for a neighbor who wants this ASAP.
However, in his case, he’s fine powering it directly via USB from the motherboard instead of sourcing power from the AB line.

I understand I should skip D1. Are there any other components I can also omit to reduce the price of the board ?

Thanks a lot for the guidance!

tchlyah, 2025-10-03:
Also, there is a couple of components in shortage, can I safely replace them with:
- U4 (ESP-12F) by [ESP-12F(ESP8266MOD)](https://jlcpcb.com/partdetail/AiThinker-ESP_12F_ESP8266MOD/C82891)
- ZD1, ZD2 (NCP1117DT33G) by [LD1117ADT33TR](https://jlcpcb.com/partdetail/STMicroelectronics-LD1117ADT33TR/C157401)

makusets, 2025-10-03:
> Also, there is a couple of components in shortage, can I safely replace them with:
> - U4 (ESP-12F) by [ESP-12F(ESP8266MOD)](https://jlcpcb.com/partdetail/AiThinker-ESP_12F_ESP8266MOD/C82891)
> - ZD1, ZD2 (NCP1117DT33G) by [LD1117ADT33TR](https://jlcpcb.com/partdetail/STMicroelectronics-LD1117ADT33TR/C157401)

Yes, the ESP12F is fine, the LD1117 too, I'm not sure what you mean with ZD1 and ZD2, did you have to replace them as well? You can skip U2 as well, that's the DCDC buck to power from AB line.

If you want, I'll send you a board for free, if you pay the postage.

Miquel

tchlyah, 2025-10-03:
> I'm not sure what you mean with ZD1 and ZD2

Sorry I meant U7!

> I'm not sure what you mean with ZD1 and ZD2

Thank you so much, but he needs 5 boards as he also have 5 units. However I'll gladly pay for the new board once you validate it!

Can you please validate the order before I make it? Thank you so much

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

| Top Designator | JLCPCB Part # | Comment          | Footprint                                |
|----------------|---------------|------------------|------------------------------------------|
| C2             | C12891        | 22u              | C1206                                    |
| C4             | C110253       | 100nF            | C1206                                    |
| D3,D5          | C2892326      | 1N4001_C2892326  | SOD-123FL_L2.8-W1.8-LS3.7-RD             |
| Q1,Q2,Q3,Q4    | C416011       | MMBT2222ALT3G    | SOT-23-3_L2.9-W1.3-P1.90-LS2.4-BR        |
| R1             | C113307       | 100Ω             | R1206                                    |
| R2,R6          | C102218       | 5.11kΩ           | R1206                                    |
| R3,R11,R12,R13,R14 | C17902     | 10kΩ             | R1206                                    |
| R4,R5,R8       | C4410         | 1kΩ              | R1206                                    |
| R7,R10         | C25830        | 22kΩ             | R1206                                    |
| R9             | C25361        | 200Ω             | R1206                                    |
| U1,U5          | C2936042      | PC817B_C2936042  | SOP-4_L6.5-W4.6-P2.54-LS10.2-BL          |
| U4             | C82891        | ESP-12F          | WIRELM-SMD_ESP-12F                       |
| U6             | C2988369      | GT-USB-7010ASV   | USB-C-SMD_G-SWITCH_GT-USB-7010ASV        |
| U7             | C157401       | NCP1117DT33G     | TO-252_L6.5-W6.1-P4.58-LS9.9-BR          |
| U8             | C7464026      | CH340C_C7464026  | SOP-16_L10.0-W3.9-P1.27-LS6.0-BL         |
| U9             | C557685       | XY308-2.54-2P    | CONN-TH_XY308-2.54-2P                    |
| ZD1,ZD2        | C21570        | BZT52C13_C21570  | SOD-123_L2.8-W1.8-LS3.7-RD               |

tchlyah, 2025-10-03:
> [@tchlyah](https://github.com/tchlyah) where are you based? Do you have any additional boards? Willing to split?

I'm based on UAE, the cost of delivery will be probably too much, and from JLCPCB you have to order by an increment of 5 anyway, so I think it will probably cost you less to order directly

makusets, 2025-10-03:
> @tchlyah where are you based? Do you have any additional boards? Willing to split?

I'm getting a new version of the board done that hopefully should be more robust and work across more models. In case you want to wait.

mtthidoteu, 2025-10-04:
> > [@tchlyah](https://github.com/tchlyah) where are you based? Do you have any additional boards? Willing to split?
>
> [@mtthidoteu](https://github.com/mtthidoteu) I'm getting a new version of the board done that hopefully should be more robust and work across more models. In case you want to wait.

Yes! I'd be very happy to wait!

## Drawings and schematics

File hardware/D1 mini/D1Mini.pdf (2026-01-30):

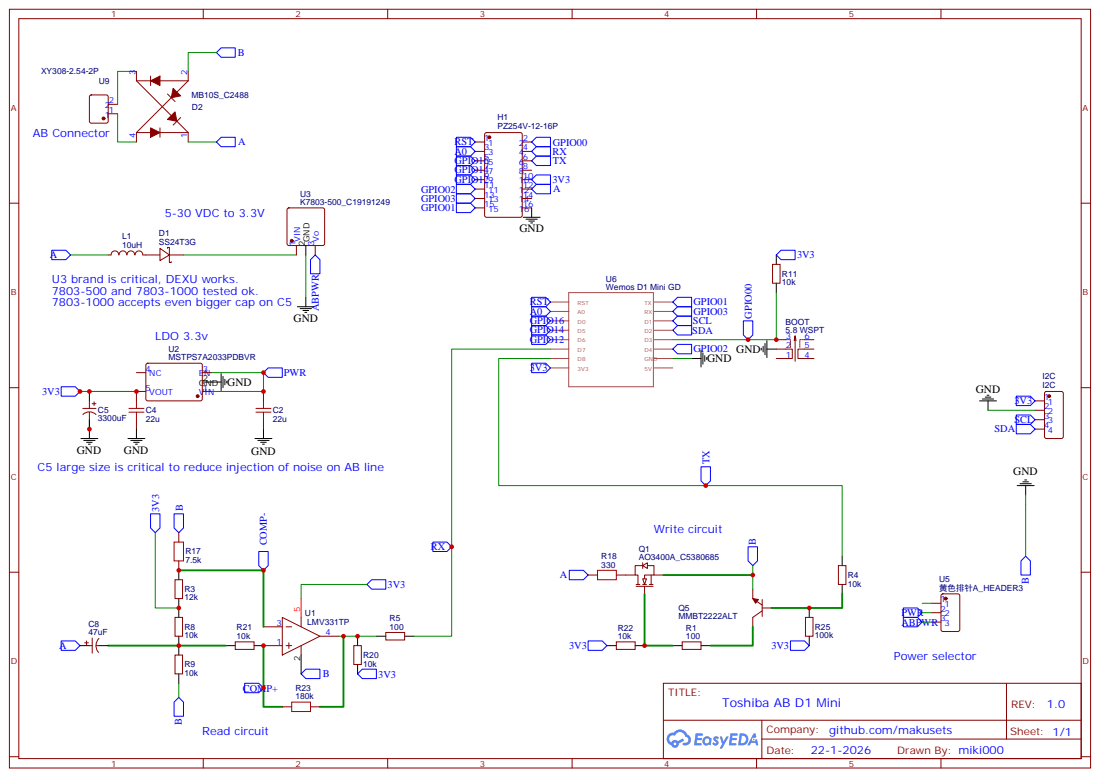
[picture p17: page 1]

U3 brand is critical, DEXU works.
7803-500 and 7803-1000 tested ok.
7803-1000 accepts even bigger cap on C5

GND
C5 large size is critical to reduce injection of noise on AB line

Company: github.com/makusets

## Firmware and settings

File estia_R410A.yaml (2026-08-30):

###############################################################################
# Complete ESPHome config example for Toshiba Estia R410A hydronic heat pumps
# using first-generation Estia frames on the AB-bus.
#
# Protocol: Estia first-generation TU2C-style protocol at 2400 baud 8N1
# Important: this is NOT the R32 Estia A0 protocol. For R32/A0 systems, use
# example_estia.yaml instead.
###############################################################################

substitutions:
  device_name: toshiba-estia-r410a
  friendly_name: "Toshiba Estia R410A"

esphome:
  name: ${device_name}
  friendly_name: ${friendly_name}

esp8266:
  board: esp12e

# Disable serial logging so the hardware UART is available for the AB bus.
logger:
  baud_rate: 0
  level: DEBUG

api:

ota:
  password: "your_ota_password"

wifi:
  ssid: !secret wifi_ssid
  password: !secret wifi_password
  ap:
    ssid: "Estia R410A Fallback"
    password: "your_ap_password"

web_server:
  port: 80

external_components:
  - source:
      type: git
      url: https://github.com/makusets/esphome-toshiba-ab
    refresh: 0s

# AB-bus UART for Estia first-generation frames.
# Use parity NONE for R410A Estia frames.
# Adjust the pins for your board revision if needed.
uart:
  tx_pin: GPIO15
  rx_pin: GPIO13
  baud_rate: 2400
  parity: NONE
  rx_buffer_size: 2048

climate:
  - platform: toshiba_ab
    name: ${friendly_name}
    id: toshiba_estia

    # Required for R410A Estia frames.
    # This format is not auto-detected, so set it explicitly.
    frame_format: estia

    # Optional diagnostic binary sensor: true when valid traffic has been seen.
    connected:
      name: "Estia Connected"

    # Optional diagnostic sensor: number of frames that failed checksum/CRC validation.
    failed_crcs:
      name: "Estia Failed CRCs"

    # Optional binary sensor: true when a first-generation remote status error is detected,
    # false again after a remote status OK frame is received.
    remote_error:
      name: "Estia Remote Error"

    # Optional, defaults to false. Set true to send the automatic
    # first-generation remote error reset command after error 0x49.
    autoreset_errors: false

    # First-generation Estia control switches.
    # Zone 1 controls the main space-heating/cooling zone.
    zone1_switch:
      name: "Estia Zone 1"

    # Switch to activate boost mode for domestic-hot-water operation.
    dhw_boost:
      name: "Estia DHW Boost"
      
    # Read-only Zone 1 values decoded from status frames
    zone1_water_temperature:
      name: "Toshiba Estia Zone 1 Water Temperature"
    zone1_target_temperature:
      name: "Toshiba Estia Zone 1 Target Temperature"


    # Heating-state binary sensors decoded from hot-water status flags.
    hotwater_pump_heating:
      name: "Estia Hot Water Pump Heating"

    hotwater_resistor_heating:
      name: "Estia Hot Water Resistor Heating"


    # Optional generic first-generation Estia sensor queries. These poll extra
    # information from the master unit, using the specific sensor addresses,
    # and publish the returned raw value multiplied by the scale below.
    # Not every unit supports every sensor; watch logs for "sensor not available"
    # responses and remove unsupported entries.
    
    sensors:
      - address: 0x6A           # Address is required for every sensor added, in this case, AC current sensor of the external unit
        scale: 0.1              # default 1.0; here we decode raw/10 as current is reported in deciAmps
        interval: 30s           # default 5min
        sensor:
          name: "Estia System Current"  # name is required
          id: toshiba_current  # optional, but needed if used later in other yaml entries

          #all other available options of sensor in esphome:

          unit_of_measurement: "A"  #optional, defaults none
          accuracy_decimals: 2  #optional
          device_class: current  #optional but recommended for HA
          state_class: measurement  #optional but recommended for HA

      - address: 0x61        # Address is required for every sensor added, in this case, outdoor temperature sensor of the external unit
        sensor:
          name: "Estia Outdoor Temperature" #required
          unit_of_measurement: "°C" 



#********************** Possible sensor addresses, not all of them available in all units ****************************************


# Control temperature (Hot water cylinder)  = 0x00
# Control temperature (Zone1)  = 0x01
# Control temperature (Zone2)  = 0x02
# Remote controller sensor temperature  = 0x03
# Condensed temperature (TC)  = 0x04
# Water inlet temperature (TWI) = 0x06
# Water outlet temperature (TWO)  =  0x07
# Water heater outlet temperature (THO) = 0x08
# Floor inlet temperature (TFI)  = 0x09
# Hot water cylinder temperature (TTW)  = 0x0A
# Mixing valve position  =   0x0B
# Low pressure (Ps) × 1/10   =   0x0E
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

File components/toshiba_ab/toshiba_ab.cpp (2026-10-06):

#include "toshiba_ab.h"
#include "esphome.h"
#include "esphome/components/network/util.h"
#include <inttypes.h>
#include <cstring>
#include <cstdlib>
#ifdef USE_ESP8266
#include <HardwareSerial.h>
#endif


namespace esphome {
namespace toshiba_ab {



static const char *const TAG = "tcc_link.climate";

static uint16_t estia_crc16(const uint8_t *data, size_t len);

static uint8_t command_opcode_for_ack_log(const DataFrame &frame) {
  if (frame.is_tu2c()) {
    // TU2C and first-generation Estia frames are stored as
    // LEN:SRC:DST:MARKER:CLASS:OPCODE:... after stripping the F0:F0 prefix,
    // so the normal-protocol opcode1 union member aliases DST.
    return frame.size() > 5 ? frame.raw[5] : frame.opcode1;
  }

  if (frame.is_estia()) {
    // A0-protocol frames are stored after the A0:00 prefix; raw[0] is the
    // command/type byte. The normal opcode1 member aliases another header byte.
    return frame.estia_size() > 0 ? frame.raw[0] : frame.opcode1;
  }

  return frame.opcode1;
}

#ifdef USE_ESP8266
// Optional hardware UART0 instance, used for RX only when GPIO13 RX is
// auto-detected on ESP8266 (or hardware_uart_rx_pin is configured). ESPHome
// disables the Arduino global `Serial`, so we own this instance. Only begun when
// enabled.
static HardwareSerial s_bus_serial(UART0);
#endif


const LogString *opcode_to_string(uint8_t opcode) {
  switch (opcode) {
    case OPCODE_PING:
      return LOG_STR("OPCODE_PING");
    case OPCODE_PARAMETER:
      return LOG_STR("OPCODE_PARAMETER");
    case OPCODE_ERROR_HISTORY:
      return LOG_STR("OPCODE_ERROR_HISTORY");
    case OPCODE_SENSOR_QUERY:
      return LOG_STR("OPCODE_SENSOR_QUERY");
    case OPCODE_ACK:
      return LOG_STR("OPCODE_ACK");
    case OPCODE_SENSOR_VALUE:
      return LOG_STR("OPCODE_SENSOR_VALUE");
    case OPCODE_STATUS:
      return LOG_STR("OPCODE_STATUS");
    case OPCODE_TEMPERATURE:
      return LOG_STR("OPCODE_TEMPERATURE");
    case OPCODE_EXTENDED_STATUS:
      return LOG_STR("OPCODE_EXTENDED_STATUS");
    default:
      // return LOG_STR(str_sprintf("UNKNOWN OPCODE 1: 0x%02x", opcode));
      return LOG_STR("UNKNOWN");
  }
}

uint8_t temp_celcius_to_payload(float t) {
  // raw = round( (t + offset) * ratio )
  // Guard NaN: lround(NaN) is impl-defined and cast-to-uint8 was producing
  // 0xFF, which the AC decodes as 92.5°C and the wall remote displays as 92.
  // Substitute 22°C as a safe fallback before any encoding.
  if (std::isnan(t)) {
    t = 22.0f;
  }
  const float scaled = (t + TEMPERATURE_CONVERSION_OFFSET) * TEMPERATURE_CONVERSION_RATIO;
  int v = static_cast<int>(std::lround(scaled));
  if (v < 0) v = 0;
  if (v > 255) v = 255;
  return static_cast<uint8_t>(v);
}

uint8_t get_heat_cool_bits(uint8_t mode) {
  // TODO: figure the bits out:
  // https://github.com/issalig/toshiba_air_cond/blob/master/air/toshiba_serial.hpp#L285
  switch (mode) {
    case MODE_HEAT:
    case MODE_AUTO:
      return 0x55;  // 0b01010101  // = 0x01 + 0x04 * air->heat + 0x02 * air->cold;
    case MODE_COOL:
    case MODE_DRY:
    case MODE_FAN_ONLY:
      return 0x33;  // 0b00110011  // = 0x01 + 0x04 * air->heat + 0x02 * air->cold;
  }

  return 0;
}

uint8_t get_fan_bit_mask_for_mode(uint8_t mode) {
  switch (mode) {
    case MODE_HEAT:
    case MODE_AUTO:
      return 0b00100000 | 0b00001000;
    case MODE_COOL:
    case MODE_DRY:
    case MODE_FAN_ONLY:
      return 0b00010000 | 0b00001000;
  }

  return 0;
}

uint8_t encode_tu2c_fan(uint8_t fan) {
  // TU2C uses bits 1-3 for the fan speed and keeps bit 5 set in every
  // climate mode. This differs from the encoding used by TCC-Link and Estia.
  return static_cast<uint8_t>((fan << 1) | 0b00100000);
}

// Byte 4 of a TU2C frame (after LEN:SRC:DST) is a constant 0xC0
static constexpr uint8_t TU2C_FRAME_MARKER = 0xC0;

uint8_t calculate_tu2c_crc(const uint8_t *data, size_t size) {
  // Plain 8-bit sum of all frame bytes from LEN up to the last data byte.

  uint16_t sum = 0;
  for (size_t i = 0; i < size; i++) {
    sum += data[i];
  }
  return static_cast<uint8_t>(sum & 0xFF);
}

bool ToshibaAbClimate::is_own_tx_echo_(const DataFrame *f) const { // used to filter out echo from our last command sent
  if (!this->last_tx_frame_for_echo_.has_value() || f == nullptr) return false;
  if ((millis() - this->last_tx_frame_millis_) > ECHO_MATCH_WINDOW_MS) return false;
  const auto &tx = this->last_tx_frame_for_echo_.value();  // last frame we wrote
  if (f->size() == tx.size() && std::memcmp(f->raw, tx.raw, f->size()) == 0) return true;

  // First-generation Estia uses the TU2C reader path. On some adapters the
  // local TX can be echoed back with slightly different wrapper/timing state,
  // so fall back to dropping recent frames that still have our Estia source,
  // current master destination and known local command/query markers.
  // Maybe not needed????
  if (this->data_reader.frame_format() == FrameFormat::ESTIA && f->is_tu2c() && f->size() >= 6 &&
      f->raw[1] == this->remote_address_ && f->raw[2] == this->master_address_ &&
      f->raw[3] == 0xE0 && (f->raw[4] == 0x01 || f->raw[4] == 0x41)) {
    return true;
  }

  return false;
}

void ToshibaAbClimate::remember_tx_frame_for_echo_(const uint8_t *bytes, size_t size, bool tu2c) {
  if (bytes == nullptr || size == 0 || size > DATA_FRAME_MAX_SIZE + 3) {
    return;
  }

  const uint8_t *payload = bytes;
  size_t payload_size = size;
  bool payload_tu2c = tu2c;

  if (size >= 4 && bytes[0] == 0xF0 && bytes[1] == 0xF0 && bytes[size - 1] == 0xA0) {
    payload = bytes + 2;
    payload_size = size - 3;
    payload_tu2c = true;
  }

  if (payload_size == 0 || payload_size > DATA_FRAME_MAX_SIZE) {
    return;
  }

  DataFrame tx{};
  std::memcpy(tx.raw, payload, payload_size);
  if (tx.size() == 0 || tx.size() != payload_size) {
    return;
  }

  tx.set_tu2c(payload_tu2c);
  this->last_tx_frame_for_echo_ = tx;
  this->last_tx_frame_millis_ = millis();
}

void ToshibaAbClimate::update_frame_validation_() {
  const bool allow_same = this->autonomous_ && !this->announce_ack_received_;
  this->data_reader.set_allow_same_source_dest(allow_same);
}

void ToshibaAbClimate::confirm_frame_format_(FrameFormat format, const char *reason) {
  if (!this->should_auto_detect_frame_format_()) {
    return;
  }
  this->data_reader.set_frame_format(format);
  this->frame_format_confirmed_ = true;
  this->apply_default_master_address_for_frame_format_();
  const char *fmt = "normal";
  switch (format) {
    case FrameFormat::TU2C: fmt = "tu2c"; break;
    case FrameFormat::A0: fmt = "a0"; break;
    case FrameFormat::HM: fmt = "hm"; break;
    case FrameFormat::ESTIA: fmt = "estia"; break;
    default: fmt = "n"; break;
  }
  ESP_LOGI(TAG, "Auto-detected frame_format=%s (%s)", fmt, reason != nullptr ? reason : "confirmed frame");
}
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

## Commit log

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2025-11-09 corrected schematic
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2025-12-21 Fix climate trait feature flag constants
    [toshiba_ab.cpp, toshiba_ab.h]
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2026-01-11 Comment out frame source check logic
    Comment out code that ignores frames with the same source and destination.
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2026-01-11 Refactor ESPHome YAML configuration for Toshiba AC
    Updated the ESPHome YAML configuration for Toshiba AC unit, including adjustments to the climate and sensor settings.
2026-01-11 Update README with new features and improvements
    Added details about new features including autonomous mode, code changes for commercial systems, filter alert sensor, and refined protocol reading.
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2026-01-23 Fix frame format enum codegen
    [complete_example.yaml, toshiba_ab.cpp, toshiba_ab.h]
2026-01-23 Revert documentation and example updates
    [complete_example.yaml]
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2026-01-23 Skip CRC check for wrapped frames
    [toshiba_ab.cpp, toshiba_ab.h]
2026-01-25 Fix wrapped-frame length parsing and terminator validation
    [toshiba_ab.h]
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2026-01-25 Fix wrapped frame header parsing
    [toshiba_ab.cpp]
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2026-01-25 Fix wrapped frame length handling
    [toshiba_ab.h]
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2026-02-02 Revert boot log docs in examples
    [toshiba_ab.cpp, toshiba_ab.h]
2026-02-02 Fix boot log replay on ESP8266
    [toshiba_ab.cpp, toshiba_ab.h]
2026-02-02 Fix boot log level mapping
    [toshiba_ab.cpp]
2026-02-02 Revert "Use API log level enums in Toshiba AB boot log replay"
    [toshiba_ab.cpp]
2026-02-02 Revert "Fix boot log replay handling for ESP8266 builds"
    [toshiba_ab.cpp, toshiba_ab.h]
2026-02-02 Revert "Add boot-log capture/replay and boot-log button wiring (revert docs changes)"
    [toshiba_ab.cpp, toshiba_ab.h]
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2026-02-06 Fix wrapped status AUTO mode decoding
    [toshiba_ab.cpp]
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2026-02-07 Fix TCC ACK matching to use parameter ACK signature
    [toshiba_ab.cpp, toshiba_ab.h]
2026-02-07 Replace unknown-source gating with configurable frame filtering
    [complete_example.yaml, toshiba_ab.cpp, toshiba_ab.h]
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2026-02-09 Revise hardware design for V3.2 board
    Updated hardware design section to reflect changes in board version and images.
2026-02-09 Modify GPIO pin settings and flashing instructions
    Updated GPIO pin assignments and flashing instructions for v3.2 board.
2026-02-09 Update README.md with v3.2 build instructions
    Added detailed instructions for ordering or building the board, including component sourcing and DIY tips.
2026-02-09 Fix image syntax in README.md
    Updated image syntax in README for schematic and board images.
2026-02-09 Fix image paths in README for hardware design
    Updated image paths for V3.2 schematic and board images.
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2026-02-15 Revert README and example YAML changes for raw frame action
    [toshiba_ab.cpp, toshiba_ab.h]
2026-02-15 Fix send raw frame action override signature
    [toshiba_ab.cpp, toshiba_ab.h]
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2026-03-19 Update README with D1 mini board variant information
    Added details about the D1 mini board variant and its compatibility with existing code.
2026-03-19 Revise README with v3.2 updates
    Updated README to reflect changes in GPIO pins for UART component.
2026-03-19 Update README with new autonomous mode features
    Added details about new features in autonomous mode, including usage without a controller, code changes for commercial systems, and filter alert sensor.
2026-04-14 feat: add Estia A0-protocol support for Toshiba heat pumps
    Add FrameFormat::ESTIA for Toshiba Estia heat pumps using the A0-protocol
    on the AB-bus (2400 baud, 8E1).
    Features:
    - Full bidirectional control: power on/off, mode (heat/cool), setpoint
    - CRC-16/MCRF4XX validation (poly 0x8408, init 0xFFFF)
    - Autonomous polling mode (E8:C0 temperatures, E8:C1 operating hours)
    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
2026-05-04 feat: add FrameFormat::HM for HM-range Toshiba indoors
    Adds support for HM-range indoor units (RAV-RM801BTP-E and similar)
    paired with TU2C-Link-capable outdoors (RAV-GM801ATP-E etc.). Selected
    via `frame_format: hm` (alongside the existing `n`/`tu2c`/`a0` values).
    Default `n` keeps classic TCC-Link behaviour unchanged.
    The HM dialect uses a different on-wire envelope for master broadcasts
    and remote→master frames:
    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
2026-05-10 Update README with Toshiba ESTIA Heat Pumps support
    Added support for Toshiba ESTIA Heat Pumps and updated documentation.
2026-05-10 Revise README for Toshiba R32 Heat Pumps support
    Updated documentation to reflect support for Toshiba R32 ESTIA Heat Pumps and clarified protocol differences.
2026-05-10 Update Toshiba Estia heat pump support information
    Clarified support details for Toshiba R32 Estia heat pumps and corrected a typo.
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2026-05-28 fix: HM variant control reliability and WDT stability
    Four independent fixes that surfaced together while debugging an
    RAV-RM801BTP-E install. Symptoms: wall remote stuck at 92.5 °C after
    boot, HA climate entity not responding, repeated Soft/Hardware WDT
    crashes during normal bus traffic.
    1. NaN guard in `temp_celcius_to_payload`. Before the first valid
    STATUS frame syncs `target_temperature`, the climate component
    carried NaN. A control command sent during that window encoded
    `lround(NaN * 2 + 70)` -> `static_cast<uint8_t>(...)` which
    undefined-behaviour'd to 0xFF on the Xtensa toolchain. 0xFF decodes
    as 92.5 °C (0xFF/2 - 35), the AC accepted it, and the wall remote
    dis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
    [toshiba_ab.cpp]
2026-05-30 feat: opt-in hardware UART RX (ESP8266) to fix software-serial WDT crashes
    On ESP8266 the bus UART falls back to bit-banged software serial when the
    pins aren't a hardware-UART pair (v3/v3.2 boards: TX=GPIO12/GPIO10, RX=GPIO13).
    The software-serial RX interrupt busy-waits ~1 character time per byte at 2400
    baud, starving Wi-Fi until the hardware watchdog resets the chip every few
    minutes on a busy HM bus (makusets#88).
    Add an opt-in `hardware_uart_rx_pin` (GPIO3 or GPIO13). When set, RX runs on
    the real hardware UART0 (swapped for GPIO13) — FIFO-backed, no busy-wait —
    while TX stays on the configured software-serial tx_pin. RX is the continuous
    load (master broadcasts); TX is infrequent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
    [toshiba_ab.cpp, toshiba_ab.h]
2026-05-30 docs: add HM-range (RAV-RM / RAV-GM) section to README
    Document frame_format: hm, supported features, the tolerated-CRC and
    three-fan-speed caveats, and the tested RAV-RM801BTP-E + RAV-GM801ATP-E units.
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2026-05-31 Update README.md by removing ESP8266 notes
    Removed notes about ESP8266 RX pin behavior.
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2026-05-31 Enhance README with updated support information
    Expanded README to include additional support details and protocol changes for Toshiba ESTIA R32 Heat Pumps.
2026-06-01 Revise Toshiba protocol compatibility details
    Updated compatibility information for Toshiba protocols, including details on TCC-Link and TU2C protocols. Added support notes for Estia heat pumps and clarified differences in protocols.
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2026-06-08 Fix normal restart marker handling for sensor replies
    [toshiba_ab.h]
2026-06-17 Add autoreset for remote error reports
    [toshiba_ab.cpp, toshiba_ab.h]
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2026-06-27 Revise Toshiba AB protocols frame formats documentation
    Updated terminology and clarified descriptions for Toshiba AB protocols and frame formats. Adjusted examples and explanations for better understanding.
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2026-06-27 Remove HM-range dialect comments from FrameFormat
    Removed detailed comments regarding HM-range dialect in FrameFormat enum.
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2026-06-29 Avoid duplicate Estia frame debug logs
    [toshiba_ab.cpp, toshiba_ab.h]
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2026-06-30 Fix ESP8266 UART config type
    [toshiba_ab.cpp]
2026-06-30 Fix Estia first-gen frame length handling
    [toshiba_ab.cpp, toshiba_ab.h]
2026-06-30 Fix DHW current temperature polling
    [toshiba_ab.cpp, toshiba_ab.h]
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2026-07-03 Limit Estia collision detection to remote pings
    [toshiba_ab.cpp]
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2026-07-03 Refactor Estia configuration and update logging level
    Updated logging level to DEBUG and refined comments for clarity. Removed unused configuration options and added new sensor definitions.
2026-07-03 Handle Estia first-gen remote status errors
    [toshiba_ab.cpp, toshiba_ab.h]
2026-07-03 Add Zone 1 temperature fields to YAML configuration
    Added Zone 1 water temperature and target temperature fields.
2026-07-03 Refactor logging for Estia first-gen temperatures
    Updated logging to include only temperature 2 details.
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2026-07-13 Update resistor part number in BOM_v3_2.csv
    [BOM_v3_2.csv]
2026-07-13 Fix first-gen Estia DHW command mappings
    [toshiba_ab.cpp, toshiba_ab.h]
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2026-07-18 Refactor TU2C frame marker comments and definition
    Removed redundant comments and clarified the constant definition for TU2C frame marker.
2026-07-18 Fix ACK opcode logging for wrapped frames
    [toshiba_ab.cpp]
2026-07-20 Fix power source description in README
    Corrected wording regarding power source and communication.
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2026-07-25 Modify TU2C frame examples with 'C0' suffix
    Updated TU2C frame format examples to include new suffix 'C0'.
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2026-08-01 Add remote error diagnostic and reset limit
    [toshiba_ab.cpp, toshiba_ab.h]
2026-08-02 Correct TU2C fan command encoding
    [toshiba_ab.cpp]
2026-08-03 Exclude successful frames from reset error rate
    [toshiba_ab.cpp, toshiba_ab.h]
2026-08-03 Report reader noise rate without sender restarts
    [toshiba_ab.cpp, toshiba_ab.h]
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2026-08-05 Handle remote announce address collisions
    [toshiba_ab.cpp, toshiba_ab.h]
2026-08-15 Create 'Other' issue template with detailed fields
    Added a new issue template for 'Other' issues with fields for board type, machine type, model number, details, and optional photos.
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2026-08-30 Fix A0 sensor queries and ACK filtering
    [toshiba_ab.cpp]
2026-09-06 Revise README for UART pins and AC wire instructions
    Updated instructions for UART pin selection and AC wire disconnection.
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2026-09-16 Fix Estia Zone 1 current temperature source
    [example_estia.yaml, toshiba_ab.cpp]
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2026-09-16 Refine comments and protocol details in example_estia.yaml
    Updated comments for clarity and corrected protocol references.
    [example_estia.yaml]
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2026-09-28 Short frame len = 13 for R32 1A frames
    [toshiba_ab.cpp]
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2026-10-06 Update ESPHome YAML with new wifi and climate options
    Added output power configuration to wifi section and optional remote address for climate control.
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2026-10-12 Fix wall-mounted louvre broadcast destination and master ACK matching
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2026-10-13 Fix classic TCC-Link Auto status decoding (0x06 -> HEAT_COOL)
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2026-10-23 Correct regular TU2C temperature report prefix to 61 38 01
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2026-10-31 Fix first-generation ESTIA cooling target commands
    Select the captured cooling setpoint payload and accept 7-25 C targets. Preserve the existing heating payload and range, selected mode while Off, pending mode changes and transmission guards. Replay the actual controller packet through the climate control path and document the visual configuration and hardware-validation limits.
2026-10-31 Respect retained ESTIA Auto mode when Zone 1 is Off
    Resolve the controller-selected mode before deciding whether to send a fixed setpoint. An Off climate state must not hide retained weather compensation; explicit Heat/Cool requests still take precedence. Cover Off and running Auto through checksum-valid master reports.
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2026-11-02 fix(tests): restore missing tu2c_fan_level_checks and fix switch state assertion
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
